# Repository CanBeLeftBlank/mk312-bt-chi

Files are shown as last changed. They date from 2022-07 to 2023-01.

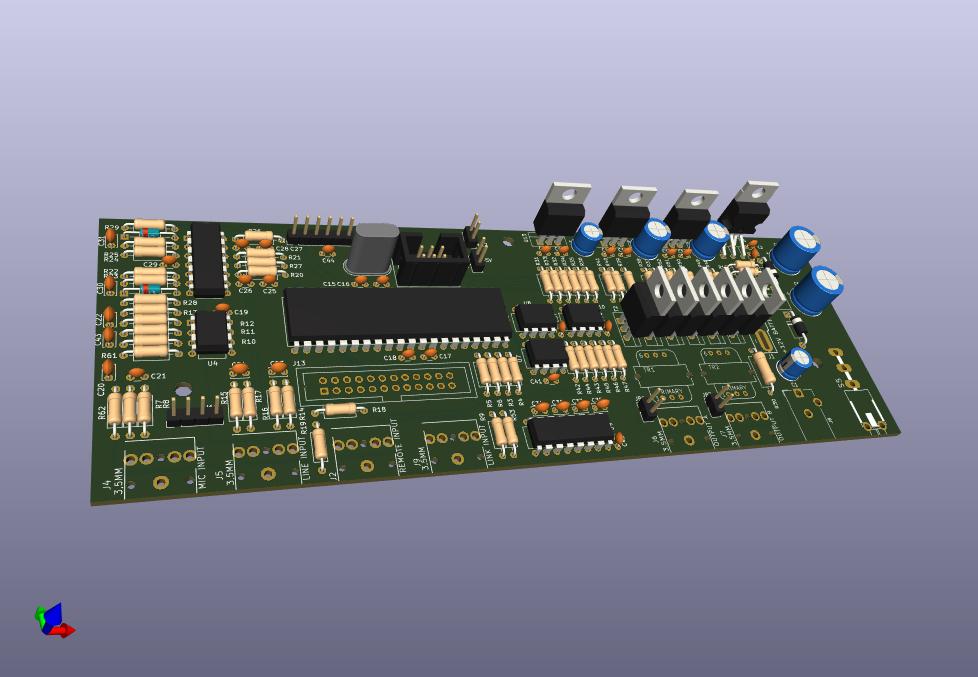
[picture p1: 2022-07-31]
kicad/mainboard/images/mainboard-1.3-chi.jpg

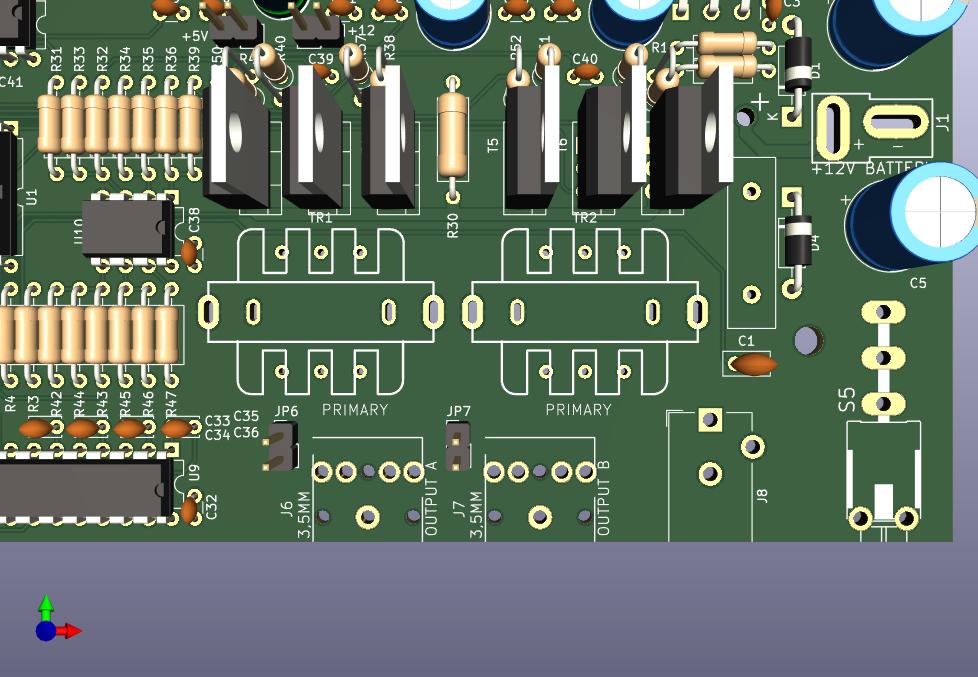
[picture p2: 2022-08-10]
kicad/mainboard/images/dual mounting holes.jpg

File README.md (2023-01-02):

Welcome to the MK-312BTχ (Chi) project. This is a fork of the project bij [CrashOverride85](https://github.com/CrashOverride85/mk312-bt) which itself is cloned from an earlier project and ultimately a project by MetaFetish that has since been removed from GitHub.

# What is it?

MK-312BTχ is a DYI electronics kit to build an Estim box, including schematics, printed circuit board layouts and parts lists. If you don't know what an Estim box is or have no experience with electronics and soldering, this project is probably not for you...

If you do know what an Estim box is: build and use at your own risk! Even though a lot of people have build these devices there's always room for error and (painful) experiences.

## How is this different from the other cloned projects?

The original designs were made with the Eagle CAD software. Since I don't have an expensive Eagle license I decided to convert the schematics to the open source KiCad format. This will hopefully allow more people to experiment with this or improve the design.

There was also an update available of the schematic (v1.4) and final board design, but only as PDFs and images. So I compared them with the old v1.3 Eagle designs and re-applied the changes in the KiCad version. This is the original v1.4χ version.

Second, documentation was always a bit lacking or confusing. This project aims to improve on that.

And who knows, maybe in the future we'll have original source code and firmware as well...

## What's with the X in the version?

It's not an X but the Greek letter χ (Chi) which is pronounced 'Kai', similar to 'KiCad'. 

# Building!

So, let's get to the main event. There are 4 parts to this:

* Getting the circuit boards
* Buying the electronic parts
* Soldering and putting it together
* Programming the firmware

Oh yes, before you continue: you must be able to program an Atmel microcontroller or have someone who can do it for you. 

## Circuit boards (PCB)

In the gerbers/ folder are the latest Gerber files as zip files, one for each of the 3 boards: the main circuit board, the display print and the front panel. Easiest is to have these boards made at a PCB factory; the front panel looks best with a black soldermask.

The zip files contain Gerber files with Protel filenames; they are known to work with at least one PCB manufacturer (PCBWay: no affiliation or sponsorship). I would like some feedback on how it fares with other manufacturers.

## The electronic parts

*As of the time of writing (December 2022), there is still a global shortage of chips and other electronic parts. However, with a little bit of creativity you can still get all the parts. For example I substituted the main processor, an ATMega16A-PU, with the ATMega16L-8PU, a low-power version that runs 'only' at 8 MHz which so happens to be the actual clockspeed. The stereo pot at the display panel is no longer available at Mouser, but AliExpress has plenty of them. And the blue LCD that is originally specified is not shipped everywhere, so I picked a green one.*

In the bom_and_info/ folder is a spreadsheet with a parts-list for Mouser; a few substitutions / replacements have been marked with colors and notes. This list has been used to get parts in August 2022, but your milage may vary. There is no BOM for other parts suppliers, but all components are standard parts so it should be easy to find them. The BOM also contains a suitable case.

There is one choice you have to make: which transformer to use. The PCB supports two types: the Xicon 42TL004 (default) and the 42TU200. The latter is bigger and should give more power on the outputs, but was until recently only available in bulk. If you buy the 42TU200 you must use a lower value for R30; see the BOM for details.

You need a short ribbon cable to connect the display to the main board. The BOM lists separate components for this but you can also buy a pre-made 24-pin ribbon cable at Amazon, EBay or AliExpress.

## Building it

In the bom_and_info/ folder there is a document with detailed building instructions, as well as 2 PDFs with component placements for the display and mainboard. You will need a soldering iron with a fine tip, some thin solder (leaded or lead-free) and a bit of free time. All parts are through-hole so easy to mount. 

With the given PCBs and case you can mount the mainboard at the bottom of the case with a few short screws; the display with front panel slides in vertically (see the images). 

## Programming the firmware

This is a bit of a gray area. There are various firmware revisions floating around on the 'Net, sometimes with names like 'buttshock'; problem is they are only available as binary files, no sources. Some have patches and fixes to the original firmware but are still binary-only. 

This repository contains an old but working version of the firmware with tweaks for the chosen LCD; this has to do with the ← and → symbols on the LCD that differs between brands.

To set your programmer fuses:

* Low fuse: 0xFF
* High fuse: 0xDC

This assumes an 8 MHz crystal is used.

On the mainboard PCB is a 6-pin header for programming, compatible with the Atmel-ICE programmer (and probably a few others). An alternative is an external programmer. There is no way to upload the firmware using a bootloader AFAIK.

# Using it

## Charging

The recommende charging voltage is 15 Volt DC; the box monitors the input voltage and if it is too high, the firmware may display an error 21. The battery will still be charged to its nominal voltage but the LM2914 might get hot due to a high charging current.

Note: as with all estim boxes it is not recommend to use the machine while it is being charged and thus (indirectly) connected to mains voltage.

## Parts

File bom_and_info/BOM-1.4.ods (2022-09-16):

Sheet: V1.4 BOM
All electronic and some hardware parts are sourced from Mouser (mouser.com); some hardware must be bought elsewhere.
This BOM is based on the original V1.3 but with a few substitutions due to part shortages at the moment of ordering (August 2022).
Parts that were out of stock have been sourced elsewhere, but the Mouser part numbers have been retained.
One particular part that may cause problems is P3, a dual pot from Alps that is obsolote and no longer stocked at Mouser. I have not been able to find a substitute yet (AliExpress may be your friend here....)
Legend
Blue | Substituted part
Red | Out of stock / unavailable
Green | Alternative supplier
Designator | Part | Value | Amount | Mouser nr | Original or alternative
ICs
U1 | Microcontroller | ATMega16A-PU | 1 | 556-ATMEGA16L-8PU | 556-ATMEGA16A-PU | No stock
U2 | OpAmp | LM324N | 1 | 595-LM324N
U3 | Analog switch | CD4066BE | 1 | 595-CD4066BE
U4, U10 | OpAmp | LM358N | 2 | 595-LM358P
U8 | DAC | LTC1661 | 1 | 584-LTC1661CN8#PBF
U9 | RS232 convertor | MAX232 | 1 | 700-MAX232CPE
U11, U12 | 9 volt regulator | 7809TV | 2 | 511-L7809CV
U13 | 5 volt regulator | 7805CV | 1 | 511-L7805CV
U14 | Adjustable voltage regulator | LM2941T | 1 | 926-LM2941T/LF03
LCD1 | LCD 16x2 characters | 162J BC BW | 1 | 758-162JBCBW |  | Original blue LCD is not shipped to consumers
Diodes
D1, D4 |  | 1N4004 | 2 | 621-1N4004
D2, D3, D5 |  | 1N4148 | 3 | 512-1N4148
Transistors
T1, T2, T4, T5 | MOSFET | IRL520N | 4 | 942-IRL520NPBF
T3, T6 | MOSFET | IRF9Z24 | 2 | 942-IRF9Z24NPBF
T7, T8 | Transistor, PNP | 2N3904 | 2 | 512-2N3904BU
Resistors
R1 | Resistor 0.25 W | 12k | 1 | 660-MF1/4DCT52R1202F
R2 | Resistor 0.25 W | 1.2k | 1 | 660-MF1/4DCT52R1201F
R3, R10, R20, R21, R27, R29, R31, R32, R33, R34, R36, R43, R44, R45, R47, R61, R37, R40, R48, R51, R28, R42 | Resistor 0.25 W | 100k | 22 | 660-MF1/4DC1003F
R4, R11, R16, R17, R22, R24 | Resistor 0.25 W | 20k | 6 | 660-MF1/4DCT52R2002F
R5, R39, R50, R58, R63, R38, R41, R49, R52 | Resistor 0.25 W | 10k | 9 | 660-MF1/4DCT52R1002F
R6 | Resistor 0.25 W | 3.3k | 1 | 660-MF1/4DCT52R3301F
R7, R8 | Resistor 0.25 W | 2.2k | 2 | 660-MF1/4DCT52R2201F
R9, R13 | Resistor 0.25 W | 4.7k | 2 | 660-MF1/4DCT52R4701F
R12, R23, R25, R26 | Resistor 0.25 W | 1M | 4 | 660-MF1/4DC1004F | 660-MF1/4DCT52R1004F
R14, R15, R19, R62 | Resistor 0.25 W | 1k | 4 | 660-MF1/4DCT52R1001F
R18, R56, R57 | Resistor 0.25 W | 1.5k | 3 | 660-MF1/4DCT52R1501F
R30 | Resistor 0.5 W | 0.5R | 1 | 660-CF1/2CT52RR50J |  | End of life
Alternate R30 | Resistor 0.5 W | 0.27R | 1 | 660-MOX1/2CT52AR27 |  | See TR1, TR2
R35, R46 | Resistor 0.25 W | 200k | 2 | 603-MFR-25FTF52-200K |  | 660-MF1/4DCT52R2003F out of stock
R53, R59, R60, R54 | Resistor 0.25 W | 390 | 4 | 660-MF1/4DCT52R3900F
R55 | Resistor 0.25 W | 100 | 1 | 660-MF1/4DCT52R1000F
Condensatoren
C1 | Ceramic, high value | 10 uF / 50 V | 1 | 810-FG11X7R1H106KRT6
C2, C3, C9, C10, C11, C12, C13, C14, C17, C18, C19, C21, C26, C28, C29, C32, C38, C39, C40, C41, C44, C42 | Capacitor unpolarized | 0.1 uF | 22 | 80-C320C104K5R
C4, C5 | Elco, 16 Volt | 1000 uF | 2 | 647-UPW1E102MPD6
C6, C7 | Elco, 16 Volt, low ESR | 470 uF | 2 | 667-EEU-FR1C471 |  | Panasonic EEU-FR1C471
C8 | Elco, 10 Volt | 10 uF | 1 | 647-USV1H100MFD1TP
C15, C16 | Ceramic capacitor | 18 pF | 2 | 80-C315C180J1G
C20, C22, C23, C24, C30, C31, C33, C34, C35, C36, C43 | Ceramic capacitor | 1 uF | 11 | 80-C315C105K3R
C25, C27 | Ceramic capacitor | 1 nF | 2 | 80-C315C102K1G
Passive
P1,P2 | Pot, Alps, RK09L Single Vertical | 10k | 2 | 688-RK09L1140A2U |  | Out of stock
P3 | Pot, Alps, RK09L Double Vertical | 10k | 1 | 688-RK09L1240A12 |  | Obsolete, no longer stocked (!)
P4 | 10 k trimmer, Bourns | 20k | 1 | 652-3362P-1-203LF | 3362P-1-103LF | 10k sold out, 20k should work fine
MIscellaneous
XTAL1 | Crystal 8 MHz | TXC 9B-8.000MEEJ-B | 1 | 717-9B-8.000MEEJ-B
F1 | Polyfuse | 1A | 1 | 650-LVR100S-240
LED1, LED2, LED3, LED4 | LED 5mm | red | 4 | 606-4304H1
J1 | Sparkfun ‘Deans’ connector | PRT 11864 | 1 | 474-PRT-11864
J2, J3, J4, J5, J6, J7 | 3.5mm stereo jack | Kycon STX-3100-5NB | 6 | 806-STX-3100-5NB | Digikey 2092-STX-3100-5NB-ND | Also STX-3100-5N (without backplate)
J8 | DC power jack, 2.1/5.5 mm | CUI Devices PJ-002A | 1 | 490-PJ-002A
 | DC power bus | CUI Devices PP3-002AH | 1 | 490-PP3-002AH
J9 | Radio header (6 socket) |  | 1 | 538-90147-1206
J10,J11 | Pinheader IDC | 2x12 | 2 | 517-N2524-6002RB
Header sockets | 24 pin press-on | 3M 89124-0103 | 2 | 517-8924
Flatcable | 24 wires | 10 cm / 4 inches | 1
J12 | Pinheader | 2x3 |  |  |  | See LCD header
JP2 | Pinheader | 1x4 |  |  |  | See LCD header
JP3 | Pinheader | 1x2 |  |  |  | See LCD header
JP4 | Pinheader | 1x2 |  |  |  | See LCD header
JP6, JP7 | Pinheader | 1x2 |  |  |  | See LCD header
Jumpers | Jumper / shunt |  | 2 | 571-382811-6
 | LCD header, 16 pin | 1x16 | 2 | 710-61301611121 |  | One for LCD, the rest for misc. connections
S3,S1,S2,S4 | Pushbutton, square |  | 4 | 611-D6C90F2LFS |  | D6C90F2LFS
 | Gray button covers |  | 2 | 611-BTND610F
 | White button covers |  | 2 | 611-BTND600F
S5 | On/off switch |  | 1 | 611-7101-061 |  | The original part, C&K 7101K2AV2BE is a special switch with protection against accidental activiation but is very expensive. This alternative, 611-7101K2AV2BE, is cheaper and has a short lever.
TR1, TR2 | Audio transformer | Xicon 42TL004 | 2 | 42TL004-RC
Alternate TR, TR2 | Audio transformer (see R30) | Xicon 42TU200 | 2 |  |  | For a bit more power; only available in bulk
U2, U3 | 14 pin socket |  | 2 | 517-4814-3004-CP
U9 | 16 pin socket |  | 1 | 517-4816-3004-CP
U1 | 40 pin socket |  | 1 | 575-11041640410010
U10, U4, U8 | 8 pin socket |  | 3 | 571-1-2199298-2
Battery lugs | 4.8 mm | Keystone 8291 | 2 | 534-8291
Wire for battery | 18 gauge or 0.82 mm²
Mechanical
Knob | For potentiometer |  | 3 | 450-BA761
Case | PacTec | CM86-225 Black | 1 | 616-63025-510-000
Front panel bolts | Socket head screw (hex or Torx) | M2.5x20 | 6
Front panel nuts |  | M2.5 | 12
Mainboard screws | Sheet metal screw | #4x1/4 / 3 mm by 6 mm | 2

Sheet: V1.3 BOM
Number of Units Produced : | 1
Designator | Description | Quantity per Unit | Total Quantity | Supplier | Supplier Part Number | Alternate Part | Notes
R55 | RES 47R | 1 | 1 | Mouser | 660-MF1/4DC47R0F
R53,R54,R59,R60 | RES 390R | 4 | 4 | Mouser | 660-MF1/4DCT52R3900F
C10,C11,C12,C13,C14,C17,C18,C19,C2,C21,C22,C23,C24,C26,C28,C29,C3,C32,C37,C38,C39,C40,C41,C42,C43,C44,C9 | CAP 0.1uF (0.1" spacing) 50V | 27 | 27 | Mouser | 80-C320C104K5R
R30 | RES 0.5R 1/2W | 1 | 1 | Mouser | 660-CF1/2CT52RR50J
R2 | RES 1.2K | 1 | 1 | Mouser | 660-MF1/4DCT52R1201F
R18, R56,R57 | RES 1.5K | 3 | 3 | Mouser | 660-MF1/4DCT52R1501F
C4,C5 | 1000uF 16V minimum | 2 | 2 | Mouser | 647-UPW1E102MPD6
R10,R20,R21,R27,R28,R29,R3,R31,R32,R33,R34,R36,R37,R40,R42,R43,R44,R45,R47,R48,R51 | RES 100K | 21 | 21 | Mouser | 660-MF1/4DC1003F
R38,R39,R41,R49,R5,R50,R52,R58 | RES 10K | 8 | 8 | Mouser | 660-MF1/4DCT52R1002F | 660-MF1/4DC1002F
C8 | CAP 10uF | 1 | 1 | Mouser | 647-USV1H100MFD1TP
C1 | CAP 10uF CER | 1 | 1 | Mouser | 810-FG11X7R1H106KRT6 |  | Ceramic Cap in case of reverse voltage dc supply
R1A | RES 12K | 1 | 1 | Mouser | 660-MF1/4DCT52R1202F
C15,C16 | CAP 18pF | 2 | 2 | Mouser | 80-C315C180J1G
F1 | 1A POLYFUSE | 1 | 1 | Mouser | 650-LVR100S
R14,R15,R19, | RES 1K | 3 | 3 | Mouser | 660-MF1/4DCT52R1001F
R12,R23,R25,R26 | RES 1M | 4 | 4 | Mouser | 660-MF1/4DCT52R1004F
D1 | DIODE 1N4004 | 1 | 1 | Mouser | 621-1N4004
D2,D3 | DIODE 1N4148 | 2 | 2 | Mouser | 512-1N4148
C25,C27 | CAP 1nF (0.1" spacing) | 2 | 2 | Mouser | 80-C315C102K1G
C20,C30,C31,C33,C34,C35,C36 | CAP 1uF (0.1" spacing) | 7 | 7 | Mouser | 80-C315C105K3R
R35,R46 | RES 200K | 2 | 2 | Mouser | 660-MF1/4DCT52R2003F
R11,R16,R17,R22,R24,R4 | RES 20K | 6 | 6 | Mouser | 660-MF1/4DCT52R2002F
J10,J11 | PAK100/2500-24 - 2425- 3M WALL HEADER | 2 | 2 | Mouser | 517-N2524-6002RB
Q7,Q8 | TRANS. 2N3904 | 2 | 2 | Mouser | 512-2N3904BU
R6 | RES 3.3K | 1 | 1 | Mouser | 660-MF1/4DCT52R3301F
R7,R8,R9 | RES 4.7K | 3 | 3 | Mouser | 660-MF1/4DCT52R4701F
U3 | CD4066N | 1 | 1 | Mouser | 595-CD4066BE
TR1,TR2 | 42TL004 | 2 | 2 | Mouser | 42TL004-RC
C6,C7 | CAP 470uF 16V | 2 | 2 | Mouser | 647-UHE1E471MPD
R13 | RES 47K | 1 | 1 | Mouser | 660-MF1/4DCT52R4702F
U13 | VREG 7805T | 1 | 1 | Mouser | 511-L7805CV | 511-L7805ACP | Alternate part is better thermally
U11,U12 | VREG 7809TV | 2 | 2 | Mouser | 511-L7809CV
XTAL1 | 8MHZ XTAL HC-49S | 1 | 1 | Mouser | 717-9B-8.000MEEJ-B
U1 | ATMEGA 16P | 1 | 1 | Mouser | 556-ATMEGA16A-PU | http://www.digikey.com/short/3fb4z5
LCD1 | LCD HD44780LCD-1602 | 1 | 1 | Mouser | 763-0216K1Z-NSW-BBW | 763-0216K1Z-NSW-FBW
Q3,Q6 | MOSFET IRF9Z24 | 2 | 2 | Mouser | 942-IRF9Z24NPBF
Q1,Q2,Q4,Q5 | MOSFET IRL520N | 4 | 4 | Mouser | 942-IRL520NPBF
JP1 | ISP 6 PIN | 1 | 1 | Mouser | 571-5-146254-3
U14 | LM2941 | 1 | 1 | Mouser | 926-LM2941CT/NOPB
U2 | LM324N | 1 | 1 | Mouser | 595-LM324N | 595-LM324NE3
U10,U4 | LM358N | 2 | 2 | Mouser | 512-LM358N
U8A (OPTIONAL - RECOMMEND USING U8B INSTEAD) | MAX548 | 0 | 0 | Mouser | 700-MAX548ACPA |  | For V1.5 and below firmware.We suggest using U8B LTC1661 purchased from Digikey (see below)
LED1,LED2,LED3,LED4 | 5MM LED | 4 | 4 | Mouser | 606-4304H1
U9 | MAX232 | 1 | 1 | Mouser | 700-MAX232CPE
SOCKET FOR U2,U3 | DIL 14 IC SOCKET | 2 | 2 | Mouser | 517-4814-3004-CP
SOCKET FOR U9 | DIL 16 IC SOCKET | 1 | 1 | Mouser | 517-4816-3004-CP
SOCKET FOR U1 | DIL 40 IC SOCKET | 1 | 1 | Mouser | 575-11041640410010
SOCKET FOR U10,U4,U8(A/B) | DIL 8 IC SOCKET | 4 | 4 | Mouser | 571-1-2199298-2
JP6,JP7 | 2x1 SIP HEADER 0.1" | 2 | 2 | Mouser | 571-5-146285-2
JUMPER | 0.1" JUMPER | 3 | 3 | Mouser | 571-382811-6
VR1, VR2 | ALPS 9mm 10K Pot | 2 | 2 | Mouser | 688-RK09L1140A2U
VR3 | ALPS 9mm 10K Dual Gang Pot | 1 | 1 | Mouser | 688-RK09L1240A12
VR4 | Bourns 3362P 10K Pot | 1 | 1 | Mouser | 3362P-1-103LF
S1,S2,S3,S4 | Buttons | 4 | 4 | Mouser | 611-D6C90F2LFS
J2,J3,J4,J5,J6,J7 | 3.5mm stereo jack | 6 | 6 | Mouser | 806-STX-3100-5NB
J8 | 2.1/5.5mm DC jack | 1 | 1 | Mouser | 490-PJ-002A
S5 | Toggle Switch with safety actuator | 1 | 1 | Mouser | 611-7101K2AV2BE | 611-7101K2AV2QE
J9 | Radio Header | 1 | 1 | Mouser | 538-90147-1206
PACTEC Case | Case | 1 | 1 | Mouser | 616-63025-510-000 | Suggest buying directly from PACTEC or sourcing a compatible case elsewhere http://bit.ly/2iuAHbB . UK SOURCE : http://uk.rs-online.com/web/p/consoles-desktop-enclosures/1047312/
Gray button covers | Button Cover | 2 | 2 | Mouser | 611-BTND610F | 611-BTND690F
White button covers | Button Cover | 2 | 2 | Mouser | 611-BTND600F
LCD HEADER | LCD Header | 1 | 1 | Mouser | 710-61301611121
KNOB | Potentiometer KNOB | 3 | 3 | Mouser | 450-BA761
BAT1 (Recommended Option) | Lead Acid Battery 2.5AH | 1 | 1 | Mouser | 547-PS-1220 | UK SOURCE http://uk.rs-online.com/web/p/lead-acid-rechargeable-batteries/5375444/
BAT1 (Option) | Lead Acid Battery 1.4AH | 0 | 0 | Mouser | 547-PS-1212
BAT 1 LUGS | Lugs For Connecting to BAT1 | 2 | 2 | Mouser | 534-8291 |  | Crimp on Lugs for Battery
Power Supply 15V (Option) | 15V, > 1A , 5.5MM OD Plug | 0 | 0 | Mouser | 709-GST25U15-P1J
Power Supply 18 V (Recommended Option) | 18V, 1A , 5.5MM OD Plug | 1 | 1 | Mouser | 709-GST18U18-P1J |  | Suggest using 18V version to give linear regulator a bit more headroom . 15V will *just barely* work
IDC connectors for ribbon cable | Ribbon Cable Connector(or buy a ready made cable) | 2 | 2 | Mouser | 517-8924 |  | Suggest sourcing a ready made cable . See misc hardware below
24 conductor ribbon cable | Bare Ribbon Cable (or buy a ready made cable) | 1 | 1 | Mouser | 517-3365/24-100 |  | See above.
Radio | HC-05 Bluetooth Module | 1 | 1 | Amazon | HC-05 (multiple amazon vendors) |  | http://amzn.to/2iiOXz6
U8B | LTC1661 (For V1.6 and above firmware) | 1 | 1 | Digikey | LTC1661CN8#PBF-ND |  | This is the suggested DAC
J1 T Connector (Deans Connector)- DNF (Unless you want to , then F away) | 12V Battery Connector | 1 | 1 | Hobbyking | SKU: 015000231-0 |  | http://bit.ly/2jpP4gQ
MISC HARDWARE
Ribbon Cable 24 pin, 2.54mm pitch IDC. | Ribbon Cable | 1 | 1 | Amazon | B01BGNLPX0 |  | http://amzn.to/2jp34ay
#4 x 1/4" sheet metal screw (Main board to case) | Screw | 2 | 2 | McMaster-Carr | 90190A106 |  | http://bit.ly/2jCJuVR
M2.5 x 20mm socket head screw (Front panel screws) | Screw | 6 | 6 | McMaster-Carr | 91290A108 |  | http://bit.ly/2jhEohH
M2.5 nut (Front panel nut) | Screw | 22 | 22 | McMaster-Carr | 90591A270 |  | http://bit.ly/2jpf0Jq
18 Gauge Wire : | Battery Leads (quantity ft) | 5 | 5 | McMaster-Carr | 8054T15 |  | http://bit.ly/2jCHwER
Heat Shrink | Heat Shrink Tubing | 1 | 1 | McMaster-Carr | 7496K43 |  | http://bit.ly/2jYteSl

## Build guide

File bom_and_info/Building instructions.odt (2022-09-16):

MK-312-BTχ

September 2022

# General

You will need:

- A soldering iron with a fine tip
- Solder
- Sidecutters
- Small long-nose pliers
- A 1.5 mm hex key (aka "Alan key")

Optional:

- Desoldering braid
- Bending aid for the resistors and diodes
- General household glue

Electrostatic devices are marked with bold purple text in the document. Be careful when handling them and if possibe use an antistatic mat and/or wrist strap.

Make sure you have display-components.pdf and mainboard-components.pdf ready on your screen or printed out. This will save you a lot of time looking up component values.

# Display print

## Preparations

The shafts of the potentiometers are a bit too long; if you have the tools, cut off 5 mm of the shafts so the knobs will hide the nuts that hold the frontpanel in place.

The printing on the frontpanel is standard silkscreen ink used for PCBs; this is probably not resistant against a lot of wear and fingerprints, so you might consider coating it with clear varnish.

The sides of the round ‘LCD’ and ‘VDC’ holes in the frontpanel will remain visible; if that bothers you, use a permanent marker to blacken the sides.

## Building

First clean the board with isopropyl alcohol. Start with the IDC pin header on the back of the PCB (this is the only component on the back). The pins will sit under the LCD and it should fit, but check anyway. Watch out for solder spikes and remove then.

Continue with the resistors, capacitor, IC socket and small trimmer pot. Mount the transistors close to the PCB, but not directly on it; the holes for soldering are very small so watch out for solder bridges.

Next, mount the push buttons, but solder only one leg first! The flat side of the button should point to the top or the bottom. Put the caps on the buttons. Solder the 16 pin header with one pin only, too.

On the large potentiomers there is a small nub; this is normally used for anti-rotation but it interferes with the front panel; remove it with side cutters or small pliers.

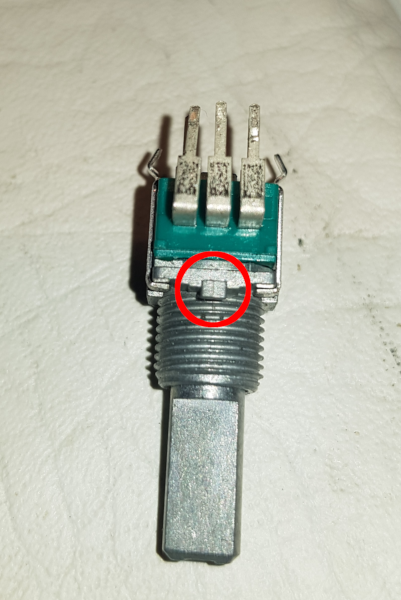
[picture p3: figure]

Solder the potientometers on the PCB, make sure they are lined up correctly; use the front panel as a guide.

Now comes the fiddly bit. Drop in the LEDs through the holes, but don’t solder them. Do the same with the LCD, placing it over the pin header but do not solder. Mount the frontpanel over the 3 potentiometers with washers and nuts; put in the 2.5 mm bolts and tighten the nuts very loosely; use the extra nuts to align the LCD with the frontpanel on the left hand side.

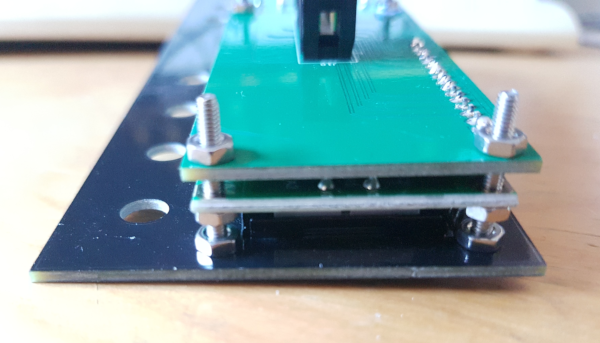
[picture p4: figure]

Check if the boards are not warped or bent, and everything is flush with the frontpanel. The buttons and LCD should stick out only a very small amount (~1 mm).

Now solder the other legs of the push buttons, make sure they don’t rub against the sides of the front panel. Solder the rest of the pin header for the LCD.

Now it’s time for the LEDs. Decide how high you want to mount them, e.g. let them stick through the front panel or slightly recessed.

Remove the frontpanel, solder the LCD to the pin header and mount the 4066 IC in its socket. Mount the frontpanel again, put the bolts back in and secure the nuts with a bit of glue.

# Mainboard

The assembly of the mainboard is pretty straightforward. Clean the board with isopropyl alcohol. Start with the diodes, resistors and small capacitors; be gentle with the 1N4148 diodes with their glass housing. Raise R30 (0.5 Watt resistor) a bit above the board, in case it gets hot. Install the crystal.

Then add the electrolytic capacitors (check polarity!), power bus connector, on/off switch, F1 polyfuse and the power regulators (LM2914, 7809 and 7805). Check for shorts and inspect your soldering so far; if all is okay, apply about 16 Volt to the power input (positive center tap); the voltage on J1 (battery connector) should be about 13.7 Volt, the charging voltage. Check the voltages of the other regulators.

You can connect the battery usig the ‘Deans’ T-shaped power connector situated between C4 and C5; it allows you to quickly swap batteries. However, you can also wire it directly to the holes below R1 and R2.

Some people don’t like to put ICs in sockets, however it is recommended to put in sockets for at least U1 (microcontroller), U9 (MAX232, external interface) and U8 (LTC1661). These components are the most likely to be damaged or are otherwise very difficult to replace. If you don’t care, put in all the IC sockets.

Now come the pin headers. There is one 6 pin female header for the radio interface and there should be a 16 pin male header that you have to break up in smaller pieces. Depending on your wishes you may not have to install any of them:

- JP2 is only needed if you want a different audio input (for example RCA jacks).
- JP6 and JP7 are only needed if you want tri-polar output (not to be confused with the firmware’s "tri-phase"). For this you must have the apropriate toys with 3 electrically separated sections; you must always use stereo jacks when you put a jumper on JP6 or JP7, as using a mono jack will short half of the output transformer.
- J9 is the female 6 pin header; you can plug in a BlueTooth receiver in here but this is entirely optional.
- J12 is a 2x3 header for programming the microcontroller, if you’re into that sort of thing.
- Finally, there are two 2-pin headers labelled ‘+5V’ and ‘+12V’ near the voltage regulators; they can be used to tap of 5 resp. 12 Volt for external circuits.

Continue with J11 (24 pin header) and the 3.5 mm jacks.

Then the transformers; the board has options for 2 different transformers: the small 42TL004 or the more powerful 42TU200. The holes in the board are spaced for the larger TU200, so carefully bend the wires of the TL004 outward in a zig-zag:

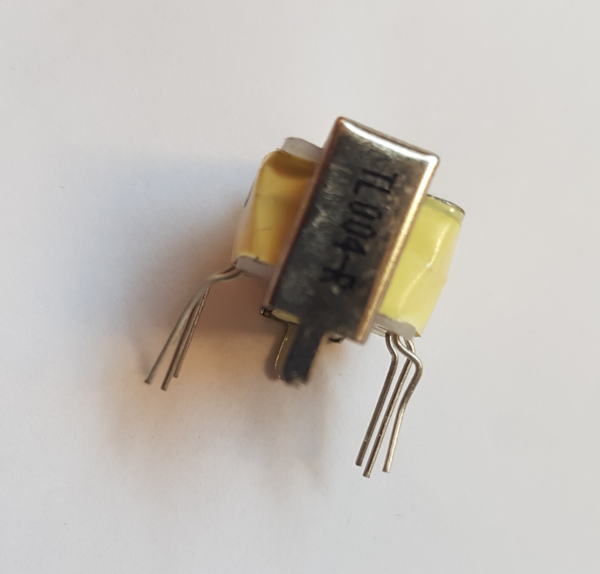
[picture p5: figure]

Note the location of the primary side! Solder the lugs of the transformer housing to the PCB.

Note that if you do install the 42TU200s you must also have the correct value for R30 (0.27 Ohm).

Finally, install the MOSFETs. Check your soldering and voltages again, then put the ICs in their sockets; note that the 40 pin ATMega16 requires quite a bit of force, push it all the way down! Connect the display to the mainboard with the flatcable. Now comes the moment of truth....

Connect the battery or an external power supply, flick the switch and when everything goes according to plan, you should be greeted with a version number and a self-test message on the display. You may have to tune the LCD contrast by adjusting the trimmer on the display print with a small screwdriver.

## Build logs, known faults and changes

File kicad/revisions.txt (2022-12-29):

Board revisions:

December 2022: 1.4.2-Chi

- Increased clearance around tracks to primary side of transformers
- Fixed annotations for R37/R38 and R48/R49 on Fab layer
- Fixed size of mounting holes for LCD
- Moved LCD window on front panel

September2022: 1.4.1-Chi

- Fixed footprint for powerbus connector

August 2022: 1.3.1-Chi

- Fixed mounting holes for display print, re-aligned LCD module.
- Tiny adjustment on mainboard for one 3.5 mm jack

August 2022: 1.3-Chi

- Converted 1.3R Eagle designs into KiCad
- Split displayboard from main PCB
- Moved a few components a tiny bit on main PCB to make room for some
  annotations

No components were added or altered. Most standard components have been
converted to KiCad versions, except a few mechanical parts like buttons,
transformers, audio jacks and switches.

Component numbers have of course changed due to the split.

============================================================================

MK-312BT V1.4 05-19-2019 

Noteable design changes:

Board reconfigured to allow 42TU200 transformers, 42TL004 still useable by bending the wires slightly during insertion.

U4B (Mic Preamp) reconfigured as recommended by TI application for an unused op-amp section.

J10 repositioned on display panel for much shorter ribbon cable.

U8A/U8B changed to U8 for LTC1661 

R63 10K added to reset line of ATMEGA.

C6 and C7 repositioned to allow better spacing from regulators.

D5 1N4148 added to DC input line for additional protection to ATMEGA incase wrong polarity power supply.

Recommendations:

C6 and C7 should be Low ESR type electrolytics.

When using 42TU200 Transformers, if higher output current is desired use 0.27 Ohm for R30, and 680uF-820uF for C6 and C7.
42TU200 transformers were tested and known to work with 0.5, 0.30 and 0.27 ohm resistors at R30.

R55 recommended 100 - 220 ohm for LCD backlight as it is a single LED in New Haven displays. 

J2-J7 can be replaced by STX-3100-5N, same part minus the plastic back cover.  https://www.mouser.com/ProductDetail/Kycon/STX-3100-5N

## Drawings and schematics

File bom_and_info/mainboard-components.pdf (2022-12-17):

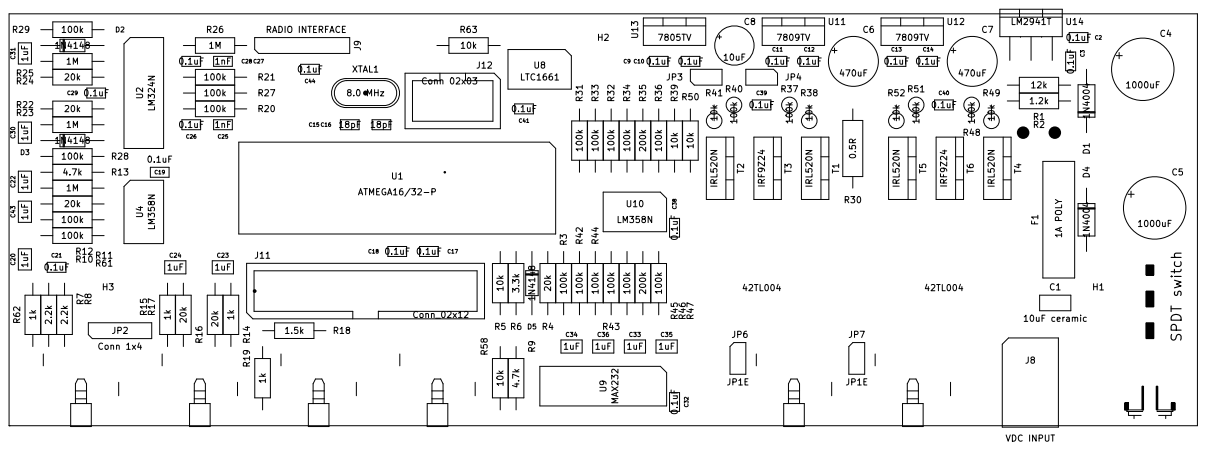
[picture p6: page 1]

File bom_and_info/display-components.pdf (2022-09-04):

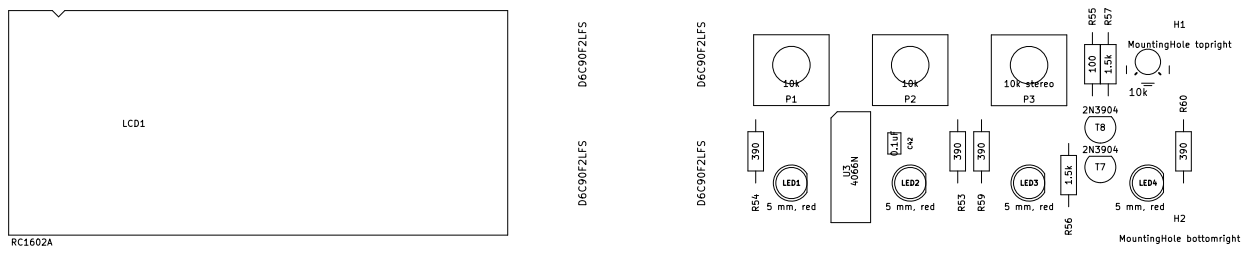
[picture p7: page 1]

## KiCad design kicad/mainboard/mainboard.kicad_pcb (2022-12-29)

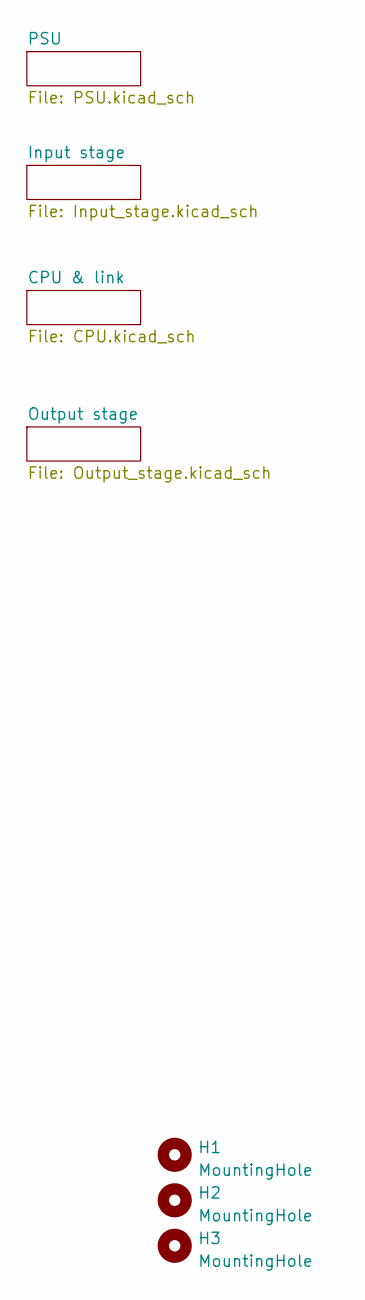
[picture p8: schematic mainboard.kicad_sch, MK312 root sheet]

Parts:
H1, H2, H3: MountingHole; MountingHole_2.5mm

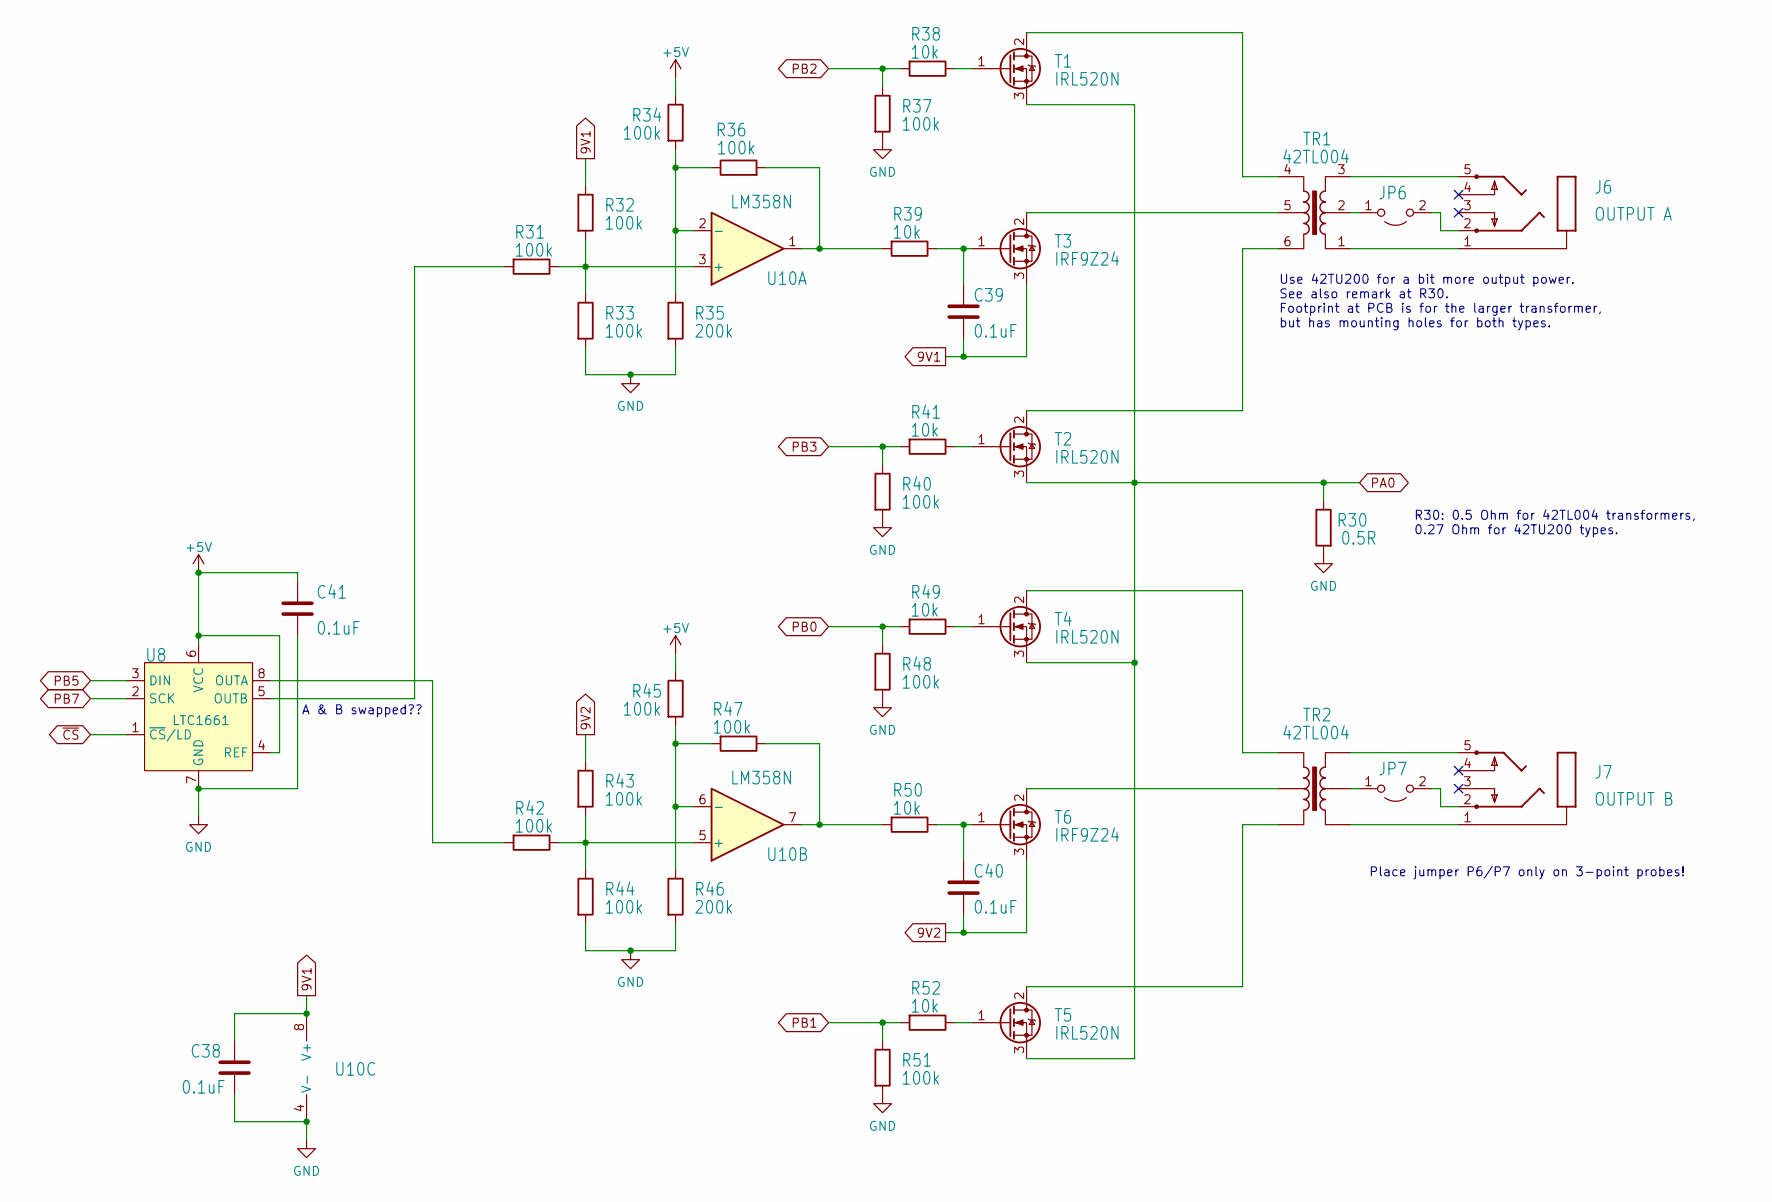
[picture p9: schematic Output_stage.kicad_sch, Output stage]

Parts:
C38, C39, C40, C41: 0.1uF; C_Disc_D3.0mm_W1.6mm_P2.50mm
J6: OUTPUT A; STX3100
J7: OUTPUT B; STX3100
JP6, JP7: JP1E; PinHeader_1x02_P2.54mm_Vertical
R30: 0.5R; R_Axial_DIN0309_L9.0mm_D3.2mm_P12.70mm_Horizontal
R31, R32, R33, R34, R36, R42, R43, R44, R45, R47: 100k; R_Axial_DIN0207_L6.3mm_D2.5mm_P10.16mm_Horizontal
R35, R46: 200k; R_Axial_DIN0207_L6.3mm_D2.5mm_P10.16mm_Horizontal
R37, R40, R48, R51: 100k; R_Axial_DIN0207_L6.3mm_D2.5mm_P2.54mm_Vertical
R38, R41, R49, R52: 10k; R_Axial_DIN0207_L6.3mm_D2.5mm_P2.54mm_Vertical
R39, R50: 10k; R_Axial_DIN0207_L6.3mm_D2.5mm_P10.16mm_Horizontal
T1, T2, T4, T5: IRL520N; TO-220-3_Vertical
T3, T6: IRF9Z24; TO-220-3_Vertical
TR1, TR2: 42TL004; Transformer_Xicon_42TL_42TU_Combi
U8: LTC1661; DIP-8_W7.62mm
U10: LM358N; DIP-8_W7.62mm

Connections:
9V1: C38.1, C39.2, R32.1, T3.3 (S), U10.8 (V+); also elsewhere on the board
9V2: C40.2, R43.1, T6.3 (S); also elsewhere on the board
+5V: C41.1, R34.1, R45.1, U8.4 (REF), U8.6 (VCC); also elsewhere on the board
GND: C38.2, C41.2, R30.2, R33.2, R35.2, R37.2, R40.2, R44.2, R46.2, R48.2, R51.2, U8.7 (GND), U10.4 (V-); also elsewhere on the board
unnamed: C39.1, R39.1, T3.1 (G)
unnamed: C40.1, R50.1, T6.1 (G)
unnamed: J6.1, TR1.1
unnamed: J6.2, JP6.2 (B)
unnamed: J6.5, TR1.3
unnamed: J7.1, TR2.1
unnamed: J7.2, JP7.2 (B)
unnamed: J7.5, TR2.3
unnamed: JP6.1 (A), TR1.2
unnamed: JP7.1 (A), TR2.2
unnamed: R31.1, R32.2, R33.1, U10.3 (+)
unnamed: R31.2, U8.5 (OUTB)
unnamed: R34.2, R35.1, R36.1, U10.2 (-)
unnamed: R36.2, R39.2, U10.1
unnamed: R38.1, T1.1 (G)
unnamed: R41.1, T2.1 (G)
unnamed: R42.1, R43.2, R44.1, U10.5 (+)
unnamed: R42.2, U8.8 (OUTA)
unnamed: R45.2, R46.1, R47.2, U10.6 (-)
unnamed: R47.1, R50.2, U10.7
unnamed: R49.1, T4.1 (G)
unnamed: R52.1, T5.1 (G)
unnamed: T1.2 (D), TR1.4
unnamed: T2.2 (D), TR1.6
unnamed: T3.2 (D), TR1.5
unnamed: T4.2 (D), TR2.4
unnamed: T5.2 (D), TR2.6
unnamed: T6.2 (D), TR2.5
PA0: R30.1, T1.3 (S), T2.3 (S), T4.3 (S), T5.3 (S); also elsewhere on the board
PB0: R48.1, R49.2; also elsewhere on the board
PB1: R51.1, R52.2; also elsewhere on the board
PB2: R37.1, R38.2; also elsewhere on the board
PB3: R40.1, R41.2; also elsewhere on the board
PB5: U8.3 (DIN); also elsewhere on the board
PB7: U8.2 (SCK); also elsewhere on the board
~CS: U8.1 (~CS/LD); also elsewhere on the board

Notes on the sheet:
A & B swapped??
R30: 0.5 Ohm for 42TL004 transformers, 0.27 Ohm for 42TU200 types.
Use 42TU200 for a bit more output power. See also remark at R30. Footprint at PCB is for the larger transformer, but has mounting holes for both types.
Place jumper P6/P7 only on 3-point probes!

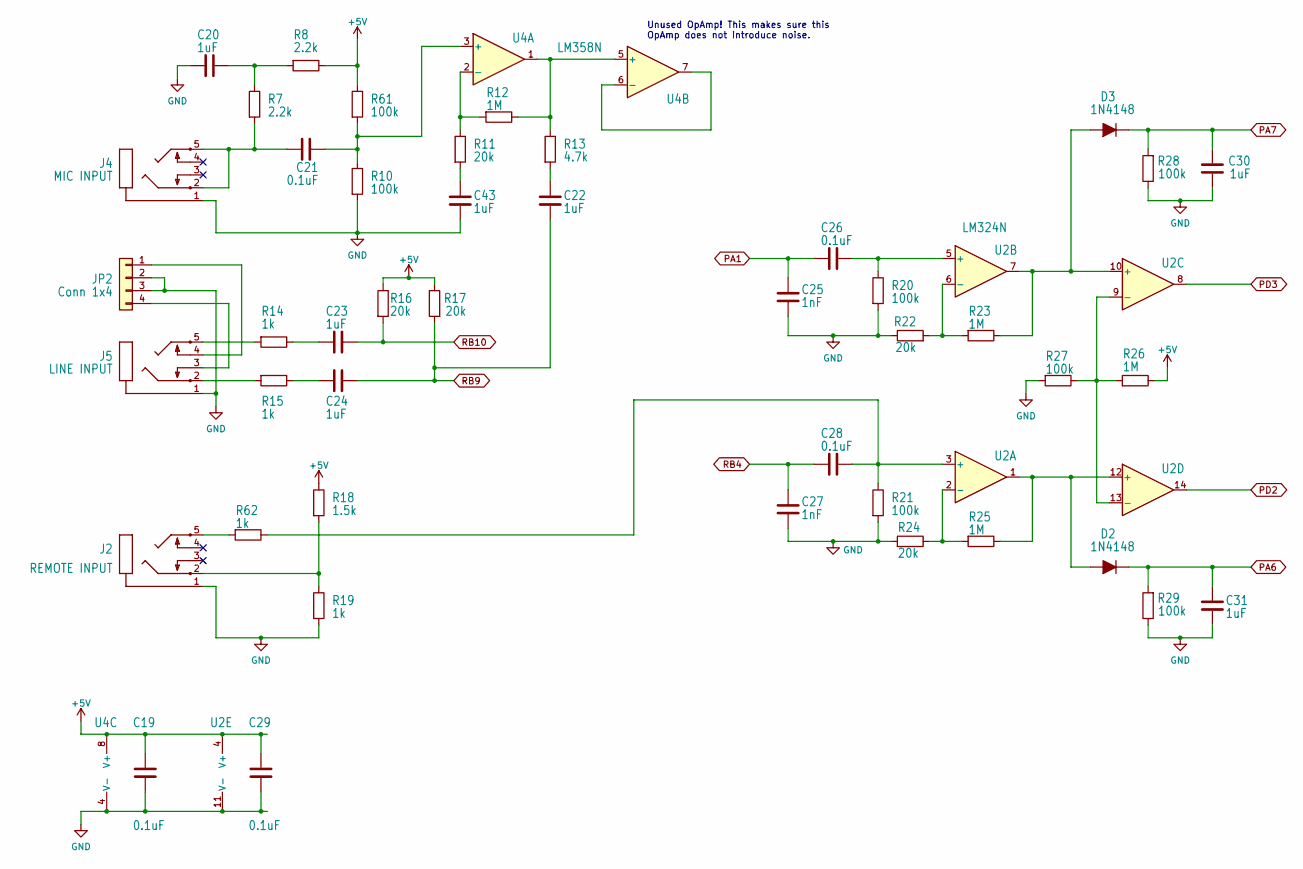
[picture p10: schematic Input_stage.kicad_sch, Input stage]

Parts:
C19, C21, C26, C28, C29: 0.1uF; C_Disc_D3.0mm_W1.6mm_P2.50mm
C20, C22, C23, C24, C30, C31, C43: 1uF; C_Disc_D3.4mm_W2.1mm_P2.50mm
C25, C27: 1nF; C_Disc_D3.0mm_W1.6mm_P2.50mm
D2, D3: 1N4148; D_DO-35_SOD27_P10.16mm_Horizontal
J2: REMOTE INPUT; STX3100
J4: MIC INPUT; STX3100
J5: LINE INPUT; STX3100
JP2: Conn 1x4; PinHeader_1x04_P2.54mm_Vertical
R7, R8: 2.2k; R_Axial_DIN0207_L6.3mm_D2.5mm_P10.16mm_Horizontal
R10, R20, R21, R27, R28, R29, R61: 100k; R_Axial_DIN0207_L6.3mm_D2.5mm_P10.16mm_Horizontal
R11, R16, R17, R22, R24: 20k; R_Axial_DIN0207_L6.3mm_D2.5mm_P10.16mm_Horizontal
R12, R23, R25, R26: 1M; R_Axial_DIN0207_L6.3mm_D2.5mm_P10.16mm_Horizontal
R13: 4.7k; R_Axial_DIN0207_L6.3mm_D2.5mm_P10.16mm_Horizontal
R14, R15, R19, R62: 1k; R_Axial_DIN0207_L6.3mm_D2.5mm_P10.16mm_Horizontal
R18: 1.5k; R_Axial_DIN0207_L6.3mm_D2.5mm_P10.16mm_Horizontal
U2: LM324N; DIP-14_W7.62mm
U4: LM358N; DIP-8_W7.62mm

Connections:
+5V: C19.1, C29.1, R8.1, R16.1, R17.1, R18.1, R26.1, R61.1, U2.4 (V+), U4.8 (V+); also elsewhere on the board
GND: C19.2, C20.2, C25.1, C27.1, C29.2, C30.1, C31.2, C43.2, J2.1, J4.1, J5.1, JP2.2, JP2.3, R10.2, R19.2, R20.2, R21.2, R22.1, R24.2, R27.2, R28.1, R29.1, U2.11 (V-), U4.4 (V-); also elsewhere on the board
unnamed: C20.1, R7.1, R8.2
unnamed: C21.1, J4.2, J4.5, R7.2
unnamed: C21.2, R10.1, R61.2, U4.3 (+)
unnamed: C22.1, R13.2
unnamed: C23.2, R14.1
unnamed: C24.2, R15.1
unnamed: C26.1, R20.1, U2.5 (+)
unnamed: C28.1, R21.1, R62.1, U2.3 (+)
unnamed: C43.1, R11.2
unnamed: D2.2 (A), R25.1, U2.1, U2.12 (+)
unnamed: D3.2 (A), R23.1, U2.7, U2.10 (+)
unnamed: J2.2, R18.2, R19.1
unnamed: J2.5, R62.2
unnamed: J5.2, R15.2
unnamed: J5.3, JP2.4
unnamed: J5.4, JP2.1
unnamed: J5.5, R14.2
unnamed: R11.1, R12.2, U4.2 (-)
unnamed: R12.1, R13.1, U4.1, U4.5 (+)
unnamed: R22.2, R23.2, U2.6 (-)
unnamed: R24.1, R25.2, U2.2 (-)
unnamed: R26.2, R27.1, U2.9 (-), U2.13 (-)
unnamed: U4.6 (-), U4.7
PA1: C25.2, C26.2; also elsewhere on the board
PA6: C31.1, D2.1 (K), R29.2; also elsewhere on the board
PA7: C30.2, D3.1 (K), R28.2; also elsewhere on the board
PD2: U2.14; also elsewhere on the board
PD3: U2.8; also elsewhere on the board
RB4: C27.2, C28.2; also elsewhere on the board
RB9: C22.2, C24.1, R17.2; also elsewhere on the board
RB10: C23.1, R16.2; also elsewhere on the board

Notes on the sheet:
Unused OpAmp! This makes sure this OpAmp does not introduce noise.

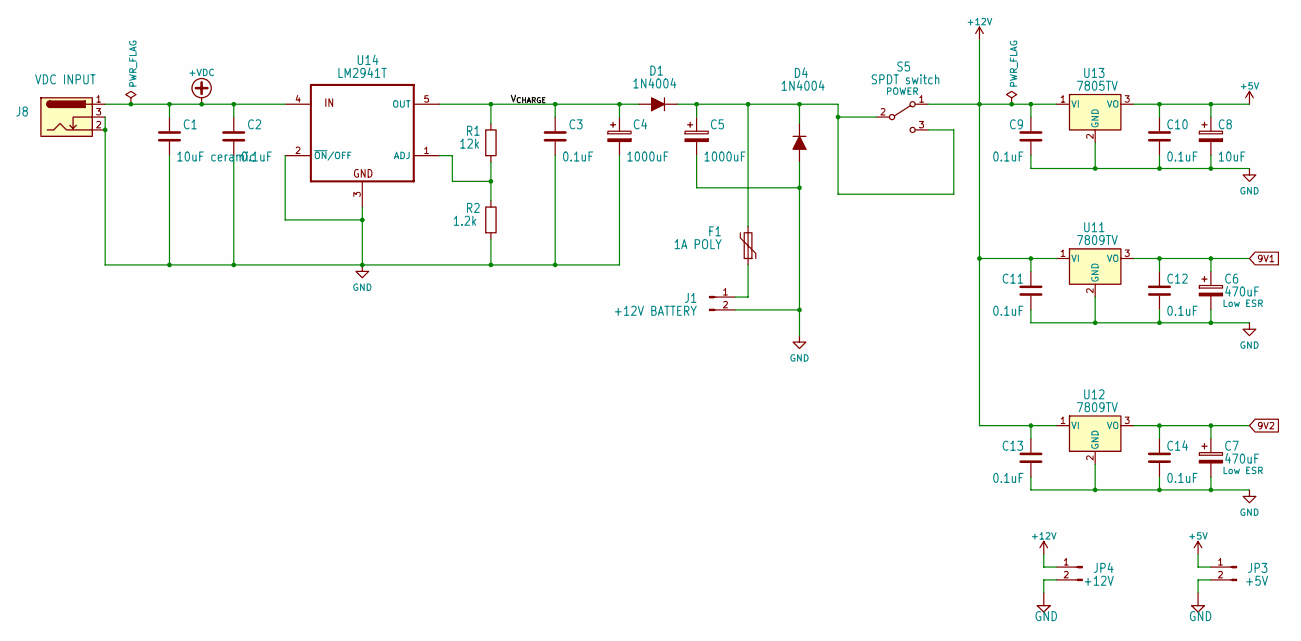
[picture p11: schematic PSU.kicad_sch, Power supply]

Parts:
C1: 10uF ceramic; C_Disc_D5.0mm_W2.5mm_P2.50mm
C2, C3, C9, C10, C11, C12, C13, C14: 0.1uF; C_Disc_D3.0mm_W1.6mm_P2.50mm
C4, C5: 1000uF; CP_Radial_D10.0mm_P5.00mm
C6, C7: 470uF; CP_Radial_D8.0mm_P3.50mm
C8: 10uF; CP_Radial_D6.3mm_P2.50mm
D1, D4: 1N4004; D_DO-41_SOD81_P10.16mm_Horizontal
F1: 1A POLY; Fuse_Littelfuse-LVR100
J1: +12V BATTERY; DEANS
J8: VDC INPUT; BarrelJack_GCT_DCJ200-10-A_Horizontal
JP3: +5V; PinHeader_1x02_P2.54mm_Vertical
JP4: +12V; PinHeader_1x02_P2.54mm_Vertical
R1: 12k; R_Axial_DIN0207_L6.3mm_D2.5mm_P10.16mm_Horizontal
R2: 1.2k; R_Axial_DIN0207_L6.3mm_D2.5mm_P10.16mm_Horizontal
S5: SPDT switch; LPV-1
U11, U12: 7809TV; TO-220-3_Vertical
U13: 7805TV; TO-220-3_Vertical
U14: LM2941T; TO-220-5_P3.4x3.7mm_StaggerOdd_Lead3.8mm_Vertical

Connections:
9V1: C6.1, C12.1, U11.3 (VO); also elsewhere on the board
9V2: C7.1, C14.1, U12.3 (VO); also elsewhere on the board
+5V: C8.1, C10.1, JP3.1, U13.3 (VO); also elsewhere on the board
+12V: C9.1, C11.1, C13.1, JP4.1, S5.1 (A), U11.1 (VI), U12.1 (VI), U13.1 (VI); also elsewhere on the board
+VDC: C1.1, C2.1, J8.1, U14.4 (IN); also elsewhere on the board
/PSU/V_{CHARGE}: C3.1, C4.1, D1.2 (A), R1.1, U14.5 (OUT)
GND: C1.2, C2.2, C3.2, C4.2, C5.2, C6.2, C7.2, C8.2, C9.2, C10.2, C11.2, C12.2, C13.2, C14.2, D4.2 (A), J1.2, J8.2, J8.3, JP3.2, JP4.2, R2.2, U11.2 (GND), U12.2 (GND), U13.2 (GND), U14.2 (~ON/OFF), U14.3 (GND); also elsewhere on the board
unnamed: C5.1, D1.1 (K), D4.1 (K), F1.2, S5.2 (B), S5.3 (C)
unnamed: F1.1, J1.1
unnamed: R1.2, R2.1, U14.1 (ADJ)

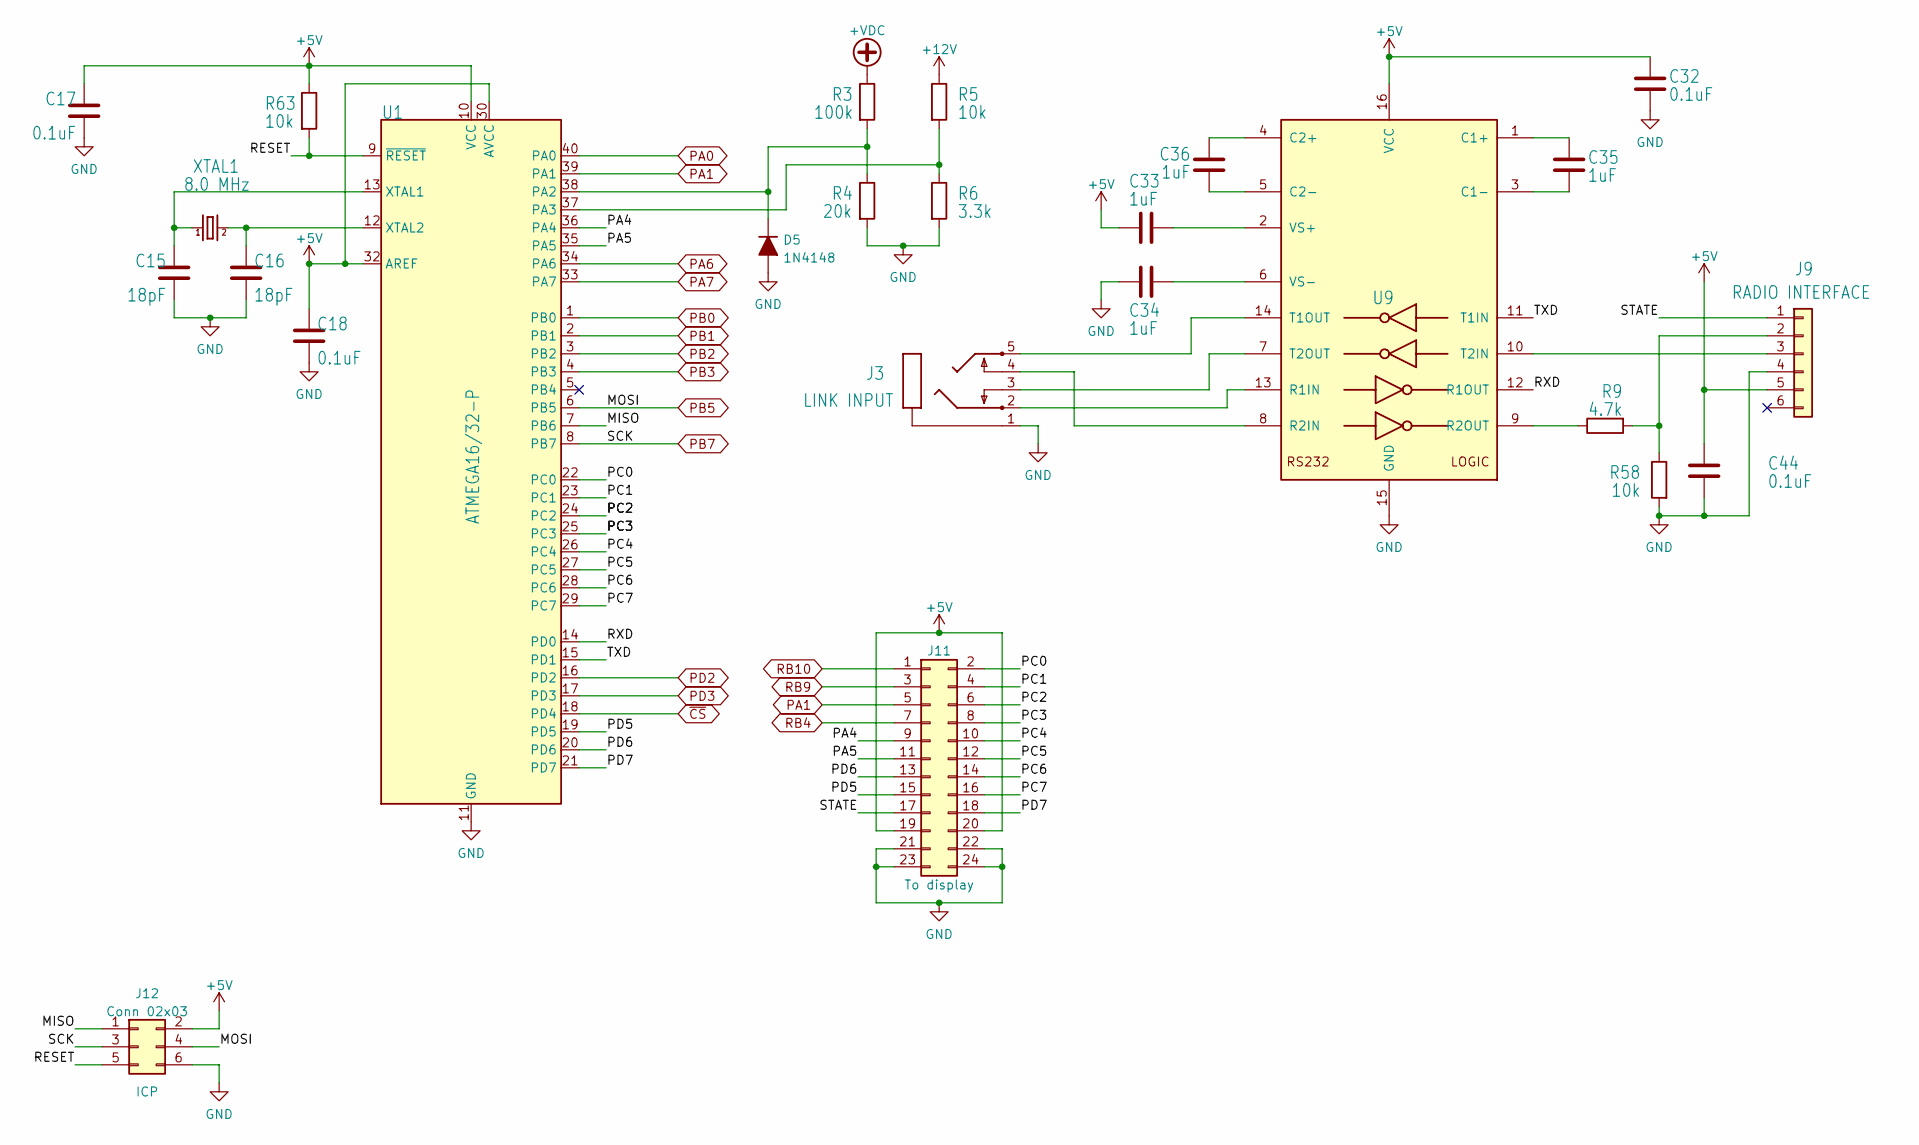
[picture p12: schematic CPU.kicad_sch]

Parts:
C15, C16: 18pF; C_Disc_D3.0mm_W1.6mm_P2.50mm
C17, C18, C32, C44: 0.1uF; C_Disc_D3.0mm_W1.6mm_P2.50mm
C33, C34, C35, C36: 1uF; C_Disc_D3.4mm_W2.1mm_P2.50mm
D5: 1N4148; D_DO-35_SOD27_P10.16mm_Horizontal
J3: LINK INPUT; STX3100
J9: RADIO INTERFACE; PinHeader_1x06_P2.54mm_Vertical
J11: Conn_02x12; IDC-Header_2x12_P2.54mm_Vertical
J12: Conn 02x03; IDC-Header_2x03_P2.54mm_Vertical
R3: 100k; R_Axial_DIN0207_L6.3mm_D2.5mm_P10.16mm_Horizontal
R4: 20k; R_Axial_DIN0207_L6.3mm_D2.5mm_P10.16mm_Horizontal
R5, R58, R63: 10k; R_Axial_DIN0207_L6.3mm_D2.5mm_P10.16mm_Horizontal
R6: 3.3k; R_Axial_DIN0207_L6.3mm_D2.5mm_P10.16mm_Horizontal
R9: 4.7k; R_Axial_DIN0207_L6.3mm_D2.5mm_P10.16mm_Horizontal
U1: ATMEGA16/32-P; DIP-40_W15.24mm
U9: MAX232; DIP-16_W7.62mm
XTAL1: 8.0 MHz; Crystal_HC49-U_Vertical

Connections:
+5V: C17.1, C18.1, C32.1, C33.2, C44.1, J9.5, J11.19, J11.20, J12.2, R63.1, U1.10 (VCC), U1.30 (AVCC), U1.32 (AREF), U9.16 (VCC); also elsewhere on the board
+12V: R5.1; also elsewhere on the board
+VDC: R3.1; also elsewhere on the board
/CPU & link/MISO: J12.1, U1.7 (PB6)
/CPU & link/PA4: J11.9, U1.36 (PA4)
/CPU & link/PA5: J11.11, U1.35 (PA5)
/CPU & link/PC0: J11.2, U1.22 (PC0)
/CPU & link/PC1: J11.4, U1.23 (PC1)
/CPU & link/PC2: J11.6, U1.24 (PC2)
/CPU & link/PC3: J11.8, U1.25 (PC3)
/CPU & link/PC4: J11.10, U1.26 (PC4)
/CPU & link/PC5: J11.12, U1.27 (PC5)
/CPU & link/PC6: J11.14, U1.28 (PC6)
/CPU & link/PC7: J11.16, U1.29 (PC7)
/CPU & link/PD5: J11.15, U1.19 (PD5)
/CPU & link/PD6: J11.13, U1.20 (PD6)
/CPU & link/PD7: J11.18, U1.21 (PD7)
/CPU & link/RESET: J12.5, R63.2, U1.9 (~RESET)
/CPU & link/RXD: U1.14 (PD0), U9.12 (R1OUT)
/CPU & link/STATE: J9.1, J11.17
/CPU & link/TXD: U1.15 (PD1), U9.11 (T1IN)
GND: C15.2, C16.2, C17.2, C18.2, C32.2, C34.2, C44.2, D5.2 (A), J3.1, J9.4, J11.21, J11.22, J11.23, J11.24, J12.6, R4.2, R6.2, R58.2, U1.11 (GND), U1.31 (GND), U9.15 (GND); also elsewhere on the board
unnamed: C15.1, U1.13 (XTAL1), XTAL1.1
unnamed: C16.1, U1.12 (XTAL2), XTAL1.2
unnamed: C33.1, U9.2 (VS+)
unnamed: C34.1, U9.6 (VS-)
unnamed: C35.1, U9.1 (C1+)
unnamed: C35.2, U9.3 (C1-)
unnamed: C36.1, U9.5 (C2-)
unnamed: C36.2, U9.4 (C2+)
unnamed: D5.1 (K), R3.2, R4.1, U1.38 (PA2)
unnamed: J3.2, U9.13 (R1IN)
unnamed: J3.3, U9.7 (T2OUT)
unnamed: J3.4, U9.8 (R2IN)
unnamed: J3.5, U9.14 (T1OUT)
unnamed: J9.2, R9.2, R58.1
unnamed: J9.3, U9.10 (T2IN)
unnamed: R5.2, R6.1, U1.37 (PA3)
unnamed: R9.1, U9.9 (R2OUT)
PA0: U1.40 (PA0); also elsewhere on the board
PA1: J11.5, U1.39 (PA1); also elsewhere on the board
PA6: U1.34 (PA6); also elsewhere on the board
PA7: U1.33 (PA7); also elsewhere on the board
PB0: U1.1 (PB0); also elsewhere on the board
PB1: U1.2 (PB1); also elsewhere on the board
PB2: U1.3 (PB2); also elsewhere on the board
PB3: U1.4 (PB3); also elsewhere on the board
PB5: J12.4, U1.6 (PB5); also elsewhere on the board
PB7: J12.3, U1.8 (PB7); also elsewhere on the board
PD2: U1.16 (PD2); also elsewhere on the board
PD3: U1.17 (PD3); also elsewhere on the board
RB4: J11.7; also elsewhere on the board
RB9: J11.3; also elsewhere on the board
RB10: J11.1; also elsewhere on the board
~CS: U1.18 (PD4); also elsewhere on the board

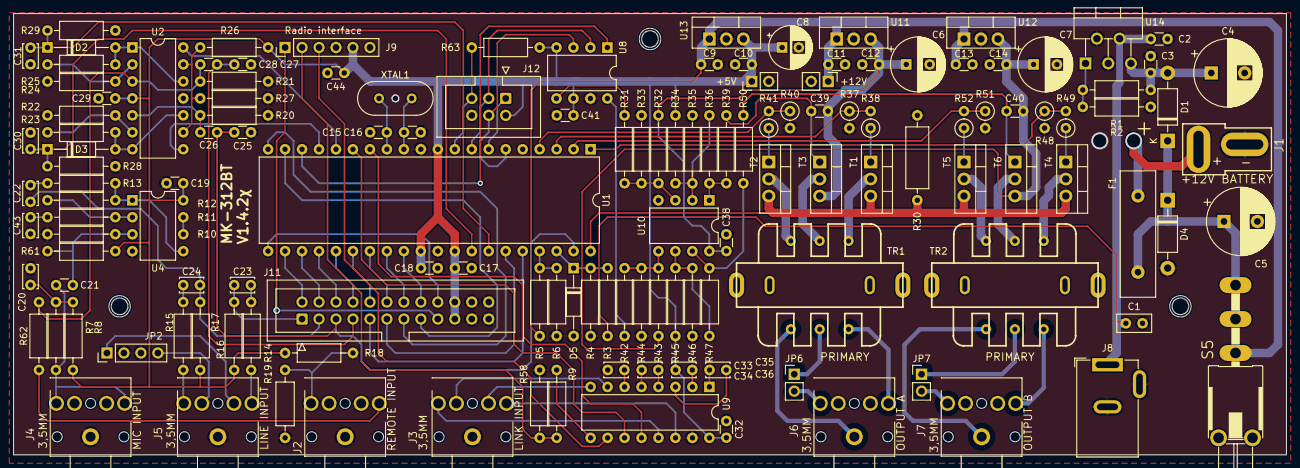
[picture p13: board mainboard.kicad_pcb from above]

Board: 2 copper layers, 190.5 x 66.0 mm, 146 parts (0 on the bottom side), 112 nets.

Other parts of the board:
@HOLE0, @HOLE1, @HOLE4: (no value)

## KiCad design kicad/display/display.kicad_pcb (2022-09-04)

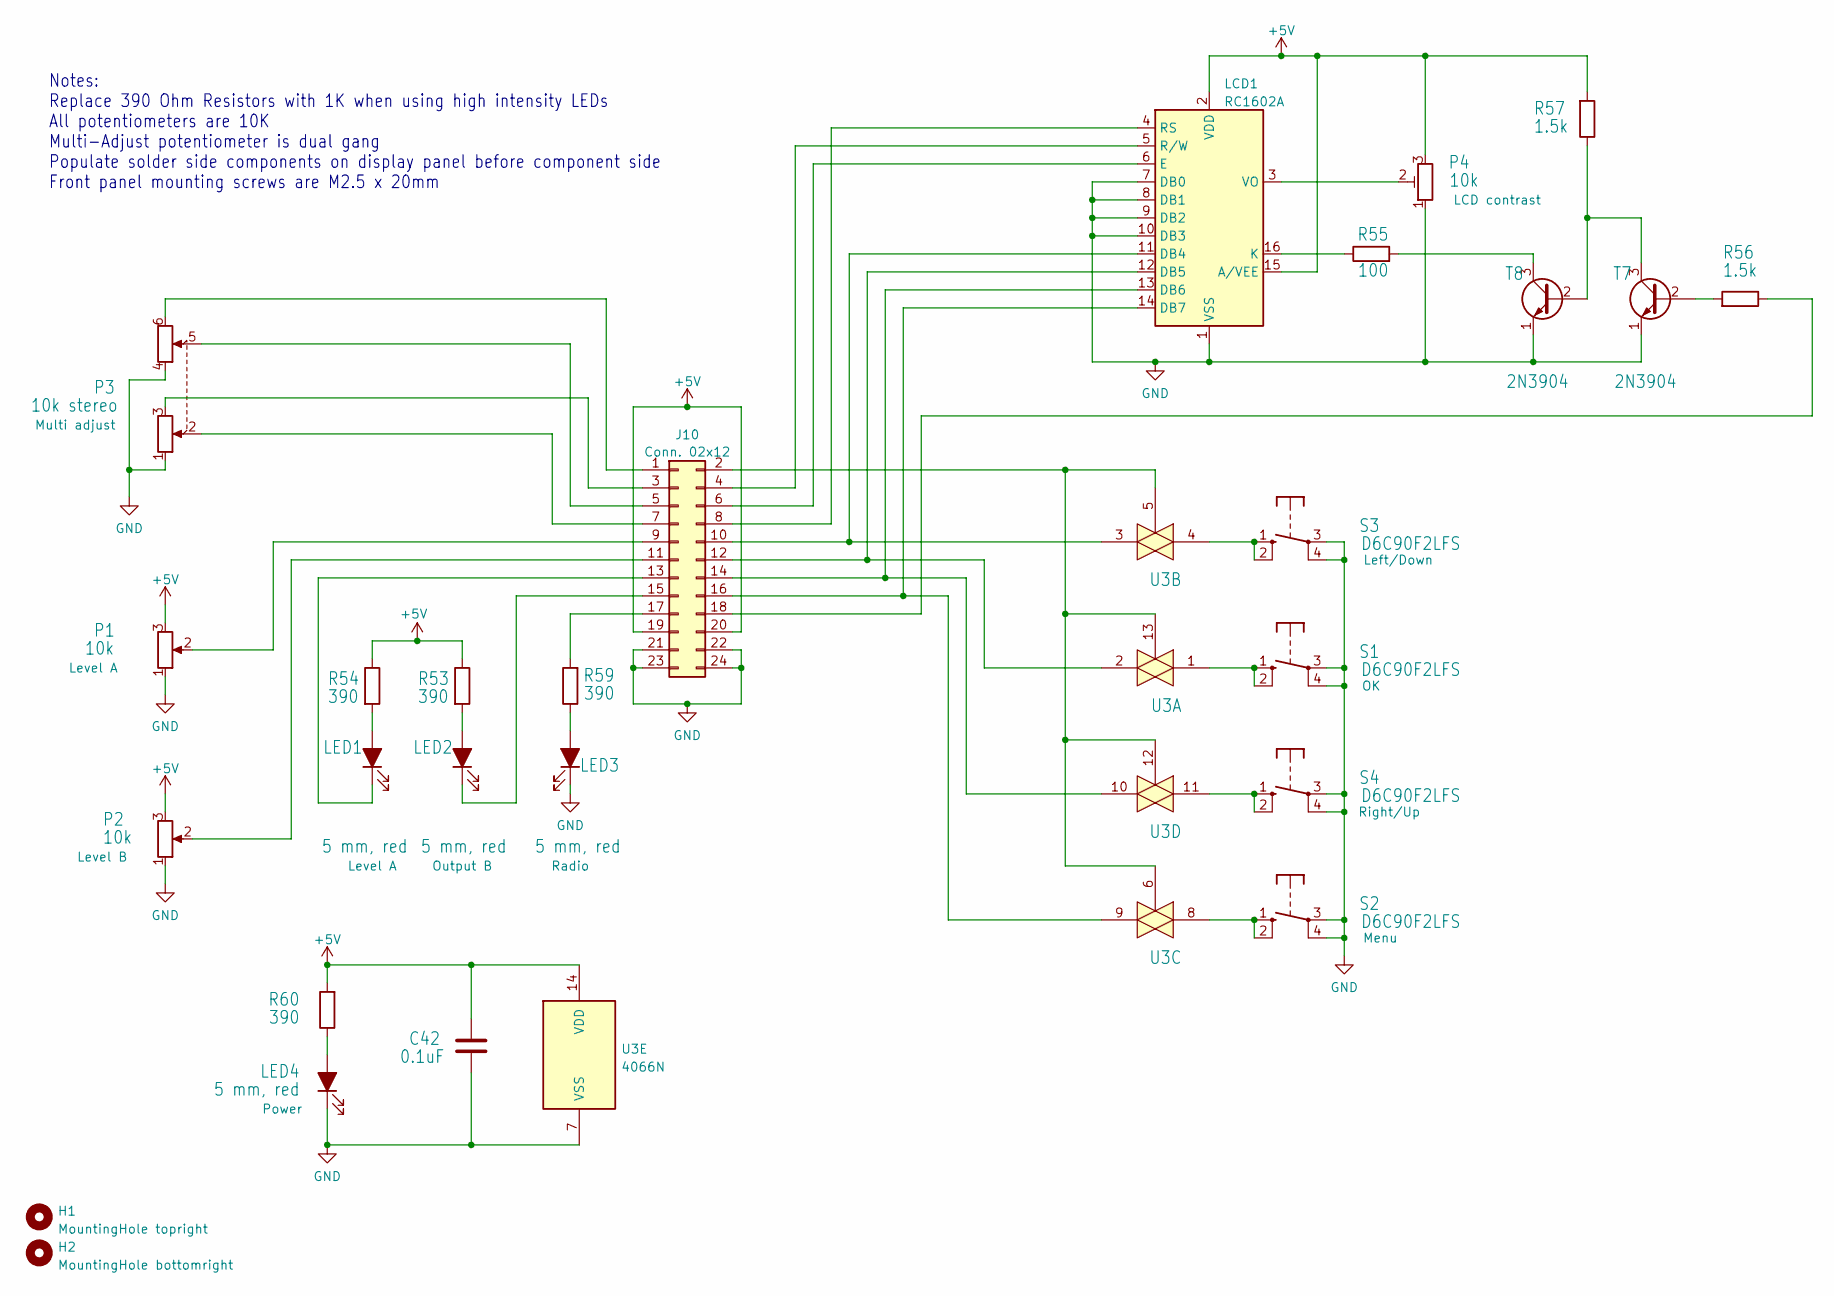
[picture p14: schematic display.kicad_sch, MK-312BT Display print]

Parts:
C42: 0.1uF; C_Disc_D3.4mm_W2.1mm_P2.50mm
H1: MountingHole topright; MountingHole_2.5mm
H2: MountingHole bottomright; MountingHole_2.5mm
J10: Conn. 02x12; IDC-Header_2x12_P2.54mm_Vertical
LCD1: RC1602A; WC1602A
LED1, LED2, LED3, LED4: 5 mm, red; LED_D5.0mm
P1, P2: 10k; Potentiometer_Alps_RK09L_Single_Vertical
P3: 10k stereo; Potentiometer_Alps_RK09L_Double_Vertical
P4: 10k; B25P
R53, R54, R59, R60: 390; R_Axial_DIN0207_L6.3mm_D2.5mm_P10.16mm_Horizontal
R55: 100; R_Axial_DIN0207_L6.3mm_D2.5mm_P10.16mm_Horizontal
R56, R57: 1.5k; R_Axial_DIN0207_L6.3mm_D2.5mm_P10.16mm_Horizontal
S1, S2, S3, S4: D6C90F2LFS; DTE6K
T7, T8: 2N3904; TO-92_Inline
U3: 4066N; DIP-14_W7.62mm

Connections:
+5V: C42.1, J10.19, J10.20, LCD1.2 (VDD), LCD1.15 (A/VEE), P1.3, P2.3, P4.3, R53.1, R54.1, R57.2, R60.2, U3.14 (VDD)
GND: C42.2, J10.21, J10.22, J10.23, J10.24, LCD1.1 (VSS), LCD1.7 (DB0), LCD1.8 (DB1), LCD1.9 (DB2), LCD1.10 (DB3), LED3.1 (K), LED4.1 (K), P1.1, P2.1, P3.1, P3.4, P4.1, S1.3, S1.4 (P@1), S2.3, S2.4 (P@1), S3.3, S3.4 (P@1), S4.3, S4.4 (P@1), T7.1 (E), T8.1 (E), U3.7 (VSS)
unnamed: J10.1, P3.6
unnamed: J10.2, U3.5, U3.6, U3.12, U3.13
unnamed: J10.3, P3.3
unnamed: J10.4, LCD1.5 (R/W)
unnamed: J10.5, P3.5
unnamed: J10.6, LCD1.6 (E)
unnamed: J10.7, P3.2
unnamed: J10.8, LCD1.4 (RS)
unnamed: J10.9, P1.2
unnamed: J10.10, LCD1.11 (DB4), U3.3
unnamed: J10.11, P2.2
unnamed: J10.12, LCD1.12 (DB5), U3.2
unnamed: J10.13, LED1.1 (K)
unnamed: J10.14, LCD1.13 (DB6), U3.10
unnamed: J10.15, LED2.1 (K)
unnamed: J10.16, LCD1.14 (DB7), U3.9
unnamed: J10.17, R59.2
unnamed: J10.18, R56.1
unnamed: LCD1.3 (VO), P4.2
unnamed: LCD1.16 (K), R55.1
unnamed: LED1.2 (A), R54.2
unnamed: LED2.2 (A), R53.2
unnamed: LED3.2 (A), R59.1
unnamed: LED4.2 (A), R60.1
unnamed: R55.2, T8.3 (C)
unnamed: R56.2, T7.2 (B)
unnamed: R57.1, T7.3 (C), T8.2 (B)
unnamed: S1.1 (S), S1.2 (S@1), U3.1
unnamed: S2.1 (S), S2.2 (S@1), U3.8
unnamed: S3.1 (S), S3.2 (S@1), U3.4
unnamed: S4.1 (S), S4.2 (S@1), U3.11

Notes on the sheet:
Notes: Replace 390 Ohm Resistors with 1K when using high intensity LEDs All potentiometers are 10K Multi-Adjust potentiometer is dual gang Populate solder side components on display panel before component side Front panel mounting screws are M2.5 x 20mm

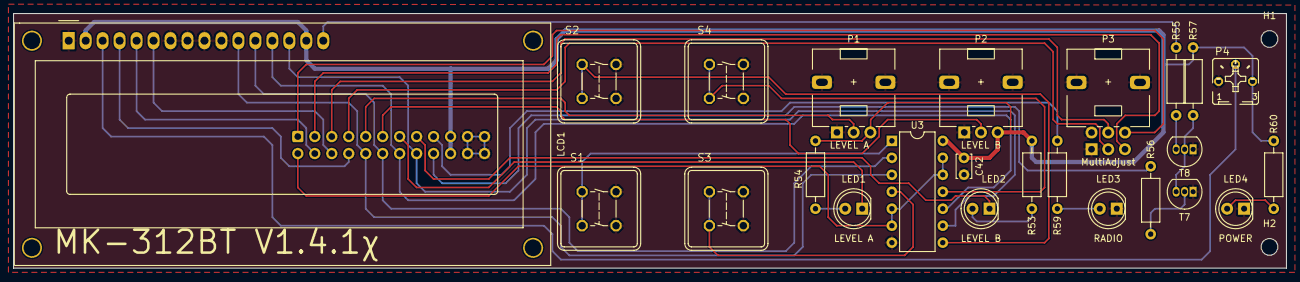
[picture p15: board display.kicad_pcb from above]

Board: 2 copper layers, 190.5 x 38.1 mm, 27 parts (1 on the bottom side), 33 nets.

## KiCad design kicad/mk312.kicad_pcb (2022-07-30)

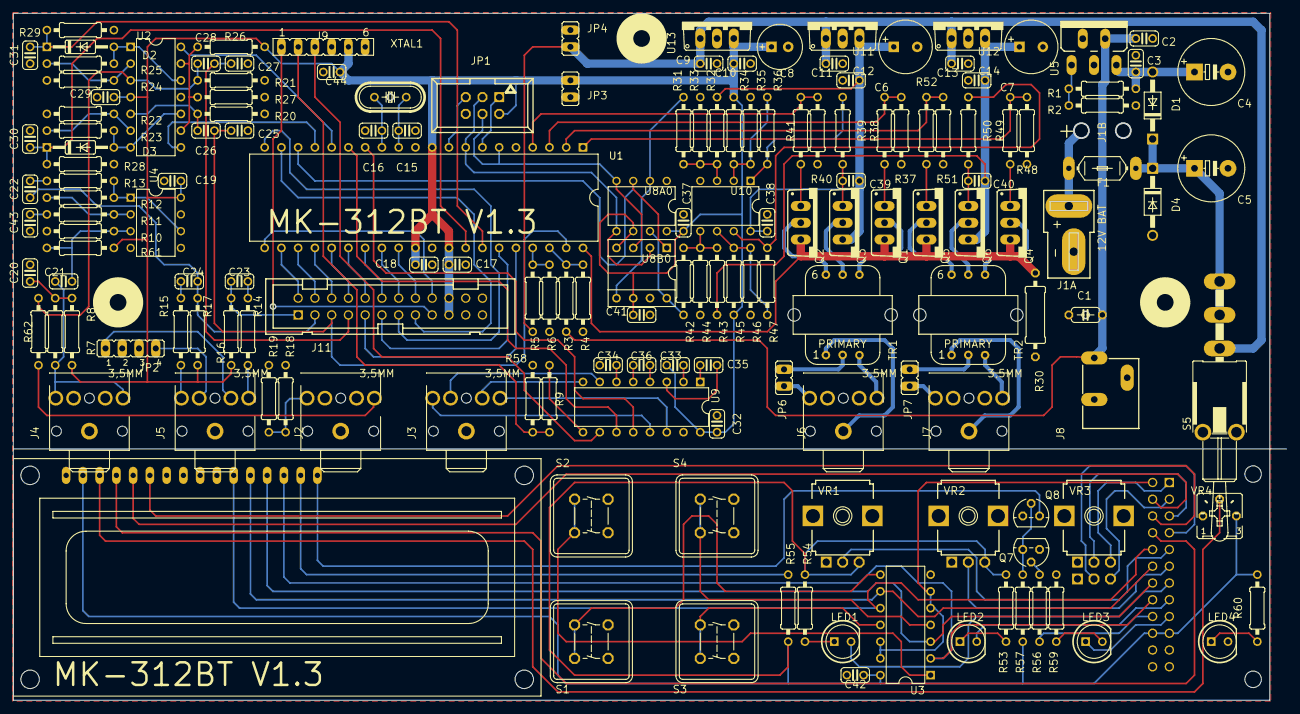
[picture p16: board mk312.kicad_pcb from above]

Board: 2 copper layers, 193.0 x 104.1 mm, 170 parts (1 on the bottom side), 131 nets.

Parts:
@HOLE0, @HOLE1, @HOLE2, @HOLE3, @HOLE4: (no value)
C1: 10uF; C050-024X044
C2, C3, C9, C10, C11, C12, C13, C14, C17, C18, C19, C21, C26, C28, C29, C32, C37, C38, C39, C40, C41, C42, C44: 0.1uF; C025-024X044
C4, C5: 1000uF; E5-10,5
C6, C7: 470uF; E3,5-8
C8: 10uF; E2,5-7
C15, C16: 18pF; C025-024X044
C20, C22, C23, C24, C30, C31, C33, C34, C35, C36, C43: 1uF; C025-024X044
C25, C27: 1nF; C025-024X044
D1, D4: 1N4004; DO41-10
D2, D3: 1N4148DO35-10; DO35-10
F1: 1A POLY; LITTLEFUSE
J1: +12V BATTERY; DEANS
J2: REMOTE INPUT; STX3100
J3: LINK INPUT; STX3100
J4: MIC INPUT; STX3100
J5: LINE INPUT; STX3100
J6: OUTPUT A; STX3100
J7: OUTPUT B; STX3100
J8: VDC INPUT; POWER_JACK_SLOT
J9: RADIO INTERFACE; FE06
J10: 2524-; PAK100_2500-24
J11: FRONT PANEL; PAK100_2500-24
JP1: ISP; 057-006-1
JP2: AUX LINE IN; JP4
JP3: +5V; JP1
JP4: +12; JP1
JP6, JP7: JP1
LCD1: HD44780LCD-1602; LCD1602
LED1: OUTPUT A; LED5MM
LED2: OUTPUT B; LED5MM
LED3: RADIO; LED5MM
LED4: POWER; LED5MM
Q1, Q2, Q4, Q5: IRL520N; TO220V
Q3, Q6: IRF9Z24; TO220V
Q7, Q8: 2N3904; TO92
R1: 12K; 0207_10
R2: 1.2K; 0207_10
R3, R10, R20, R21, R27, R28, R29, R31, R32, R33, R34, R36, R37, R40, R42, R43, R44, R45, R47, R48, R51, R61: 100K; 0207_10
R4, R11, R16, R17, R22, R24: 20K; 0207_10
R5, R38, R39, R41, R49, R50, R52, R58: 10K; 0207_10
R6: 3.3K; 0207_10
R7, R8: 2.2K; 0207_10
R9, R13: 4.7K; 0207_10
R12, R23, R25, R26: 1M; 0207_10
R14, R15, R19, R62: 1K; 0207_10
R18, R56, R57: 1.5K; 0207_10
R30: 0.5R; 0309_12
R35, R46: 200K; 0207_10
R53, R54, R59, R60: 390; 0207_10
R55: 47; 0207_10
S1: OK; DTE6K
S2: MENU; DTE6K
S3: LEFT/DOWN; DTE6K
S4: RIGHT/UP; DTE6K
S5: POWER; LPV-1
TR1, TR2: 42TL004; 42TL
U1: ATMEGA16/32-P; DIL40
U2: LM324N; DIL14
U3: 4066N; DIL14
U4, U10: LM358N; DIL08
U5: LM2941T; TO220-5
U8A0: MAX548; DIL08
U8B0: LTC1661; SOCKET-08
U9: MAX232; DIL16
U11, U12: 7809TV; TO220V
U13: 7805TV; TO220V
VR1: LEVEL A; 9MM_SNAP-IN_POT
VR2: LEVEL B; 9MM_SNAP-IN_POT
VR3: MULTI-ADJ; DUAL_9MM_SNAP-IN_POT
VR4: LCD CONTRAST; B25P
XTAL1: 8.0 MHz; HC49_S

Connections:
+5V: C8.+, C10.1, C17.1, C18.1, C19.1, C29.1, C32.1, C33.1, C37.1, C41.1, C42.1, C44.1, J9.5, J10.19, J10.20, J11.19, J11.20, JP1.2, JP3.1, LCD1.2, R8.2, R16.2, R17.2, R18.2, R26.2, R34.2, R45.2, R53.2, R54.2, R55.2, R57.1, R60.2, R61.2, U1.10, U1.30, U1.32, U2.4, U3.14, U4.8, U8A0.6, U8A0.8, U8B0.4, U8B0.6, U9.16, U13.3, VR1.3, VR2.3, VR4.E
+8V: C6.+, C12.1, C38.1, C39.2, Q3.3, R32.2, U10.8, U11.3
+9V: C7.+, C14.1, C40.2, Q6.3, R43.2, U12.3
+12V: C9.1, C11.1, C13.1, JP4.1, R5.2, S5.1, U11.1, U12.1, U13.1
GND: C1.2, C2.2, C3.2, C4.-, C5.-, C6.-, C7.-, C8.-, C9.2, C10.2, C11.2, C12.2, C13.2, C14.2, C15.2, C16.2, C17.2, C18.2, C19.2, C20.2, C25.2, C27.2, C29.2, C30.2, C31.2, C32.2, C34.2, C37.2, C38.2, C41.2, C42.2, C43.2, C44.2, D4.A, J1.-, J2.1, J3.1, J4.1, J5.1, J8.GND@1, J8.GND@2, J9.4, J10.21, J10.22, J10.23, J10.24, J11.21, J11.22, J11.23, J11.24, JP1.6, JP2.2, JP2.3, JP3.2, JP4.2, LCD1.1, LED4.K, Q7.3, Q8.3, R2.1, R4.1, R6.1, R10.1, R19.1, R20.1, R21.1, R22.1, R24.2, R27.2, R28.2, R29.2, R30.1, R33.1, R35.1, R37.1, R40.1, R44.1, R46.1, R48.1, R51.1, R58.1, R59.2, S1.3, S1.4, S2.3, S2.4, S3.3, S3.4, S4.3, S4.4, S5.B, S5.B1, U1.11, U1.31, U2.11, U3.7, U4.4, U4.5, U5.2, U5.3, U8A0.1, U8B0.7, U9.15, U10.4, U11.2, U12.2, U13.2, VR1.1, VR1.CHASSIS2, VR2.1, VR2.CHASSIS2, VR3.1, VR3.1B, VR3.CHASSIS1, VR3.CHASSIS2, VR4.A
unnamed: J10.7, VR3.2B
unnamed: R5.1, R6.2, U1.37
unnamed: R3.1, R4.2, U1.38
unnamed: S1.1, S1.2, U3.8
unnamed: S3.1, S3.2, U3.11
unnamed: Q3.2, TR1.5
unnamed: S4.1, S4.2, U3.4
unnamed: Q6.2, TR2.5
unnamed: JP7.1, TR2.2
unnamed: J10.3, VR3.3B
unnamed: J10.9, VR1.2
unnamed: J10.11, VR2.2
unnamed: J10.1, VR3.3
unnamed: C28.2, R21.2, R62.2, U2.3
unnamed: J10.5, VR3.2
unnamed: J6.1, TR1.1
unnamed: C16.1, U1.13, XTAL1.2
unnamed: Q1.1, R38.2
unnamed: Q2.1, R41.2
unnamed: J7.2, JP7.2
unnamed: C39.1, Q3.1, R39.2
unnamed: R31.2, R32.1, R33.2, U10.3
unnamed: LED2.A, R53.1
unnamed: Q4.1, R49.2
unnamed: Q5.1, R52.2
unnamed: J7.1, TR2.1
unnamed: C40.1, Q6.1, R50.2
unnamed: R42.2, R43.1, R44.2, U10.5
unnamed: LED1.A, R54.1
unnamed: LCD1.3, VR4.S
unnamed: F1.1, J1.+
unnamed: C15.1, U1.12, XTAL1.1
unnamed: R9.2, U9.9
unnamed: Q1.2, TR1.4
unnamed: J6.5, TR1.3
unnamed: Q4.2, TR2.4
unnamed: J7.5, TR2.3
unnamed: Q5.2, TR2.6
unnamed: Q2.2, TR1.6
unnamed: R34.1, R35.2, R36.1, U10.2
unnamed: R45.1, R46.2, R47.1, U10.6
unnamed: R31.1, U8A0.2, U8B0.5
unnamed: R1.1, R2.2, U5.1
unnamed: J3.5, U9.14
unnamed: C3.1, C4.+, D1.A, R1.2, U5.5
unnamed: J3.2, U9.13
unnamed: LCD1.15, R55.1
unnamed: J6.2, JP6.2
unnamed: C43.1, R11.1
unnamed: J2.5, R62.1
unnamed: JP6.1, TR1.2
unnamed: C35.1, U9.1
unnamed: R24.1, R25.1, U2.2
unnamed: D2.A, R25.2, U2.1, U2.12
unnamed: J5.2, R15.1
unnamed: J5.5, R14.1
unnamed: C23.1, R14.2
unnamed: J2.2, R18.1, R19.2
unnamed: J5.4, JP2.1
unnamed: R22.2, R23.1, U2.6
unnamed: C35.2, U9.3
unnamed: R26.1, R27.1, U2.9, U2.13
unnamed: C26.2, R20.2, U2.5
unnamed: J5.3, JP2.4
unnamed: C24.1, R15.2
unnamed: C36.2, U9.5
unnamed: C36.1, U9.4
unnamed: J9.2, R9.1, R58.2
unnamed: D3.A, R23.2, U2.7, U2.10
unnamed: C34.1, U9.6
unnamed: C21.1, J4.2, J4.5, R7.1
unnamed: C20.1, R7.2, R8.1
unnamed: C21.2, R10.2, R61.1, U4.3
unnamed: R11.2, R12.1, U4.2
unnamed: R12.2, R13.1, U4.1, U4.6
unnamed: C22.2, R13.2
unnamed: C33.2, U9.2
unnamed: C5.+, D1.C, D4.C, F1.2, S5.2, S5.3
unnamed: LED3.K, R59.1
unnamed: S2.1, S2.2, U3.1
unnamed: LED4.A, R60.1
unnamed: Q7.2, R56.1
unnamed: Q7.1, Q8.2, R57.2
unnamed: LCD1.16, Q8.1
unnamed: R42.1, U8A0.7, U8B0.8
unnamed: J10.17, LED3.A
unnamed: J3.4, U9.8
unnamed: J3.3, U9.7
unnamed: J9.3, U9.10
PA0: Q1.3, Q2.3, Q4.3, Q5.3, R30.2, U1.40
PA1: C25.1, C26.1, J11.5, U1.39
PA4: J11.9, U1.36
PA5: J11.11, U1.35
PA6: C31.1, D2.C, R29.1, U1.34
PA7: C30.1, D3.C, R28.1, U1.33
PB0: R48.2, R49.1, U1.1
PB1: R51.2, R52.1, U1.2
PB2: R37.2, R38.1, U1.3
PB3: R40.2, R41.1, U1.4
PB5: JP1.4, U1.6, U8A0.4, U8B0.3
PB6: JP1.1, U1.7
PB7: JP1.3, U1.8, U8A0.5, U8B0.2
PC0: J10.2, J11.2, U1.22, U3.5, U3.6, U3.12, U3.13
PC1: J10.4, J11.4, LCD1.5, U1.23
PC2: J10.6, J11.6, LCD1.6, U1.24
PC3: J10.8, J11.8, LCD1.4, U1.25
PC4: J10.10, J11.10, LCD1.11, U1.26, U3.10
PC5: J10.12, J11.12, LCD1.12, U1.27, U3.9
PC6: J10.14, J11.14, LCD1.13, U1.28, U3.3
PC7: J10.16, J11.16, LCD1.14, U1.29, U3.2
PD0: U1.14, U9.12
PD1: U1.15, U9.11
PD2: U1.16, U2.14
PD3: U1.17, U2.8
PD5: J10.15, J11.15, LED2.K, U1.19
PD6: J10.13, J11.13, LED1.K, U1.20
PD7: J10.18, J11.18, R56.2, U1.21
PFET_A: R36.2, R39.1, U10.1
PFET_B: R47.2, R50.1, U10.7
RB4: C27.1, C28.1, J11.7
RB9: C22.1, C24.2, J11.3, R17.1
RB10: C23.2, J11.1, R16.1
RESET: JP1.5, U1.9
STATE: J9.1, J11.17
V+: C1.1, C2.1, J8.PWR, R3.2, U5.4
~CS: U1.18, U8A0.3, U8B0.1

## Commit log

2022-07-30 Cleanup, removal of many duplicate files, re-organize files
    [MK-312BT Front Panel V1.2.brd, MK-312BT V1.2.brd, MK-312BT V1.2.sch]
2022-07-30 Import of 1.3R version into KiCad, no structural changes. Also made a small document with the changes between 1.3B and 1.3R
    [Input_stage.kicad_sch, Output_stage.kicad_sch, PSU.kicad_sch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]
2022-07-30 Conversion of display print to KiCad components; still attached to main board
    [DisplayPrint.kicad_sch, Input_stage.kicad_sch, Output_stage.kicad_sch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]
2022-07-31 Conversion of 1.3R version to KiCad!
    [CPU.kicad_sch, DisplayPrint.kicad_sch, Input_stage.kicad_sch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]
2022-08-01 Fixing mounting holes for display print
    [display.kicad_pcb, display.kicad_sch]
2022-08-01 Tiny fixups on mainboard: mounting holes and one audio jack
    [mainboard.kicad_pcb, mainboard.kicad_sch]
2022-08-01 Converted front panel as well
    [front_panel.kicad_pcb]
2022-08-07 Bringing mainboard up to par with V1.4 schematics based on images. Rerouted a few lines since they could not pass below the MOSFETs due to a different footprint/pad size.
    [CPU.kicad_sch, Input_stage.kicad_sch, Output_stage.kicad_sch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]
2022-08-09 Display print is now on parity with V1.4, but has been re-routed. U3 has also been rotated 180 degrees. Some components have been moved to other places as well
    [display.kicad_pcb, display.kicad_sch]
2022-08-10 Brought component numbers back in line with the original schematics
    [CPU.kicad_sch, Input_stage.kicad_sch, Output_stage.kicad_sch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]
2022-08-10 Adding footprint for combined Xicon 42TL or 42TU transformer; has dual mounting holes.
2022-08-10 Putting in new combined footprint for transformer. Updated F.Fab layer with component values in the correct place
    [CPU.kicad_sch, Output_stage.kicad_sch, PSU.kicad_sch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]
2022-08-10 Moving text to silkscreen layer
    [front_panel.kicad_pcb]
2022-08-13 A bit of cleanup, showing type of some OpAmps and clarification of wiring around U4
    [Input_stage.kicad_sch, Output_stage.kicad_sch]
2022-08-14 Removing copied schematics from mainboard.
    [DisplayPrint.kicad_sch, Input_stage.kicad_sch, Output_stage.kicad_sch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]
2022-08-14 Cleaning up F.Fab layer, putting values at the right places.
    [display.kicad_pcb]
2022-09-04 Add building instructions and updated BOM
    [BOM-1.4.ods, MK-312BT.ods]
2022-09-04 Fixed footprint for powerbus connector. Bumped version to 1.4.1.
    [CPU.kicad_sch, Input_stage.kicad_sch, Output_stage.kicad_sch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]
2022-09-04 Datasheets for LCD and on/off switch
2022-09-04 Two small fixups for the display & frontend. Made mounting holes in display PCB larger. Moved LCD window slightly to the right on the front panel.
    [display.kicad_pcb, display.kicad_sch, front_panel.kicad_pcb]
2022-09-16 Fixing position of R48/R49 on F.Fab layer
    [mainboard.kicad_pcb]
2022-09-16 Small textual changes in BOM and building instructions
    [BOM-1.4.ods]
2022-12-17 Fixed labels of R37 and R38 on Fab layer.
    [mainboard.kicad_pcb]
2022-12-29 Increase clearance around primary side of transformers. Moved name and version to a visible spot on the PCB silkscreen.
    [mainboard.kicad_pcb]
2022-12-29 Cleanup of old gerber files
    [MK-312BT Front Panel.GBL, MK-312BT Front Panel.GBO, MK-312BT Front Panel.GBP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]
2022-12-29 Version 1.4.2 Gerber files and revision history
2022-12-29 Removing old Eagle files and BOMs.
    [MK-312BT Front Panel V1.2.brd, MK-312BT V1.2.brd, MK-312BT V1.2.sch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]
2023-01-02 Added a bit of documentation about charging.
